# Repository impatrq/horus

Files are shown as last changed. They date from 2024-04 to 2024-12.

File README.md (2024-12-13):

<div align="center">
    
# [HORUS](https://linktr.ee/agro_horus)

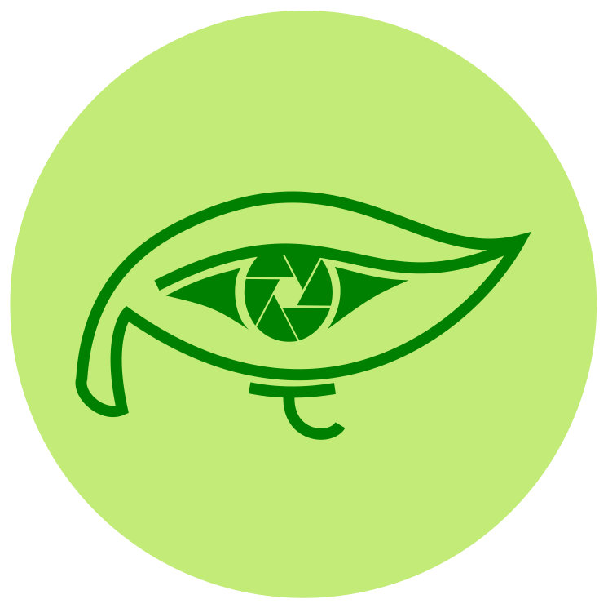
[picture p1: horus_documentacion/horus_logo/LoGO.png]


&nbsp;

| Página web | Email | Instagram | YouTube |
|---|---|---|---|
|[agro_horus.app](https://horus-pagina-web.vercel.app)|agroohoruss@gmail.com|[@agro_horus](https://www.instagram.com/agro_horus/)|[agro_horus.video](https://www.youtube.com/watch?v=Mp89aknXm1M&pp=ygUaaG9ydXMgcm9ib3Qgc2VtaWF1dG9tYXRpY28%3D)|

&nbsp;

</div>

## ¿Qué es Horus?
Horus es un robot de reconocimiento para el campo que permite la detección de plagas de manera remota.

## ¿De dónde surgió la idea?

Comenzamos primero con la idea de ayudar al campo, luego de investigación llegamos a las problemáticas que presentaban las plagas artrópodos en las plantaciones, así llegamos a la conclusión de automatizar el monitoreo de plantaciones con un robot autónomo.

## ¿Cómo funciona?
El robot se translada de manera autónoma por el campo y analiza los cultivos a su alrededor con una cámara. La IA del robot analiza el video que percibe con la cámara y determina si se encuentra con una plaga. Esta información es luego transmitida por radiofrecuencia a un módulo de comunicación que permite conectarlo a una computadora con nuestra aplicación. Esto incluye base de datos para guardar las detecciones, interfaz gráfica e interacción con el robot para el usuario

## ¿Quiénes somos?

Somos un grupo de alumnos de E.E.S.T. N°7 "Taller Regional Quilmes" (IMPA).

<div align="center">
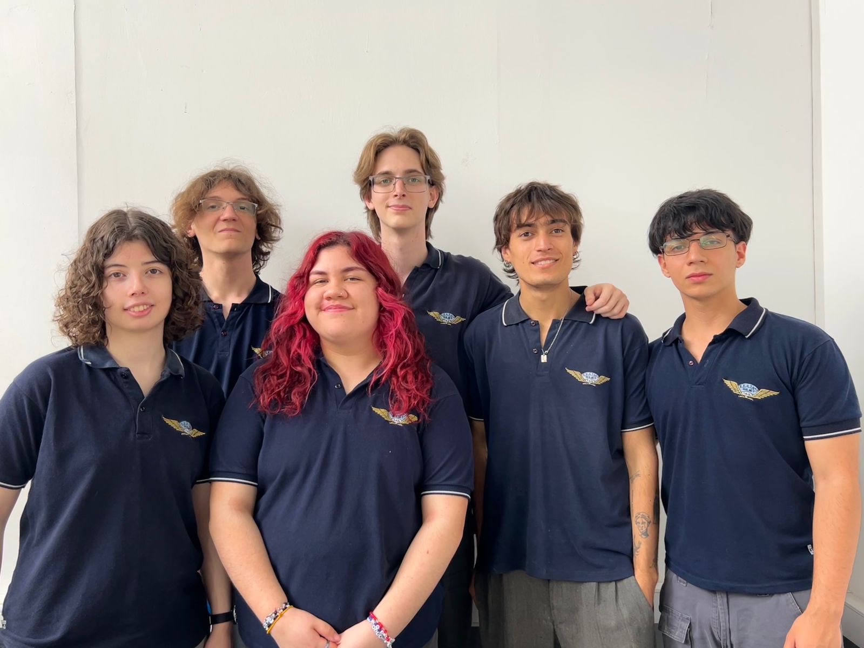
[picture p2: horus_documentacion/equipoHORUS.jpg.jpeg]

</div>

### Cabrera, Martín

* 📧 martincabreracirco@gmail.com

* LinkedIn: https://www.linkedin.com/in/mart%C3%ADn-alejandro-cabrera-6014b727b/

### Contreras, Abril Victoria

* 📷 Instagram: @_ _viicontreras__

* 📧 abrilchiscontreras@gmail.com

* LinkedIn: https://www.linkedin.com/in/abril-contreras-039998303/

### Díaz Steinbrecher, Lara

* 📧 diazsteinbrecher@gmail.com

* LinkedIn: https://www.linkedin.com/in/lara-diaz-steinbrecher-97263b303/

### Ferrante, Santino

* 📧 ferrantesantino14@gmail.com
  
* LinkedIn: https://www.linkedin.com/in/santino-marco-ferrante-a57bb5180/

### Kearney, Mateo

* LinkedIn: https://www.linkedin.com/in/mateo-kearney-996637303/

### Torres, Juan Ignacio

* 📧 juanignaciotorr@gmail.com

* LinkedIn: https://www.linkedin.com/in/juan-ignacio-torres-34a232303/

## Reconocimientos

* Medalla de Oro en PROTOTIPOS - EJE LIBRE de las ONIET 2024

* Medalla de Oro en FEED DE INSTAGRAM de las ONIET 2024

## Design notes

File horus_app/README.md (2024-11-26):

<div align="center">
    
# [HORUS APP](https://linktr.ee/agro_horus)



&nbsp;

</div>

## ¿Qué es HorusAPP?
HorusAPP es la aplicación que se usa en conjunto con Horus para que el usuario pueda interactua con él y el sistema



## Funcionalidades
* Mapa Interactivo
    * Elegir la ubicación del campo a registrar, desplazarse sobre el mapa
    * Visualizar la ubicación de uno o más robots Horus mediante un mapa
    * Insertar y visualizar ubicaciones de trampas de feromonas colocadas por los responsables del campo
    * Insertar y visualizar ubicaciones de áreas de detección que el usuario quiere que cada robot siga
    * Visualizar los reconocimientos de plaga detectados por todos los robots, y filtrar por ellos
    * Todos los marcadores tienen información sobre los mismos al presionarlos
    * Aquellos que se pueden insertar, pueden ser eliminados del sistema con doble click
    * Sistema de guardado offline para su uso en zonas sin conexión a internet
* Base de Datos que permite:
    * Guardar y exportar todos los reconocimientos hechos por todos los robots
    * Visualizar y mantener registro de cada robot, incluida su ubicación, batería y ID
    * Importar imágenes del sistema de almacenamiento externo de cada robot y hacerle zoom
    * Exportar imágenes guardadas en la base de datos como archivo comprimido
    * Filtrar y ordenar los reconocimientos hechos por los diferentes parámetros detectados:
        * Dia
        * Hora
        * Coordenadas
        * Tipo de Plaga
        * ID de Robot
        * ID de Imagen
        * Trampa de feromona
* Modos offline y online para comunicación de datos con el o los robots:
    * Online: cuando el usuario registre un robot, el servidor tratará de usar el módulo comunicador para transmitir por antena hasta conectar con un robot.
    * Offline: el usuario deberá tomar el sistema de almacenamiento externo al robot e importar los archivos de reconocimiento manualmente a la aplicación.



## Requerimientos y dependencias
* 2GB de almacenamiento en la computadora (puede escalar según el uso de la base de datos)
* 1GB de memoria
* Windows 11+, Linux o Mac
* MongoDB Compass v1.44.5
* NodeJS v20.11.1
* Dependencias: 
    * leaflet v1.9.4
    * body-parser v1.20.2
    * cors v2.8.5
    * express v4.19.2
    * mongoose v8.4.0
    * path v0.12.7
    * serialport v12.0.0
    * dotenv v16.4.5
    * @serialport/parser-readline v12.0.0
    * idb v8.0.0
    * jszip v3.10.1
    * vue v3.2.13
    * vue-router v4.0.3
    * @vue/cli-plugin-babel v5.0.0
    * @vue/cli-plugin-router v5.0.0
    * @vue/cli-service v5.0.0
    * concurrently v8.2.2
    * electron v20.2.0
    * wait-on v6.0.1 



## Instrucciones de instalación
Ingrese a la página de github de [Horus](https://github.com/impatrq/horus) y descargue el último lanzamiento. Dentro de la carpeta de horus_app, si su sistema operativo es windows, ejecute (doble click) el archivo Horus.bat; si se encuentra en Linux o Mac, ejecute el archivo Horus.sh. Para su comodidad, cree un acceso directo del archivo ejecutable (ya sea .bat o .sh) para poder acceder más fácilmente al archivo desde su escritorio.



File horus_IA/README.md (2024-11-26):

--------------------
Clonar la carpeta dentro de un entorno virtual

Instalar los requerimentos dentro del entorno
--------------------

Escribir en Terminal: 

cd yolov5

python detect.py --weights orugasmodelo.pt --source 0

(Esto activa la IA como una prueba) pero al ejecutar el main, este la activa automaticamente.

Dentro de la carpeta yolo se encuentra tambien el main.py que es el que horus ejecutara de forma constante.

--------------------

HORUS_IA

Posee la carpeta de los modelos actual y anteriores de la inteligencia artificial, asi como los programas que se utilizaron de prueba o de forma provisoria durante el proceso de creacion del prototipo

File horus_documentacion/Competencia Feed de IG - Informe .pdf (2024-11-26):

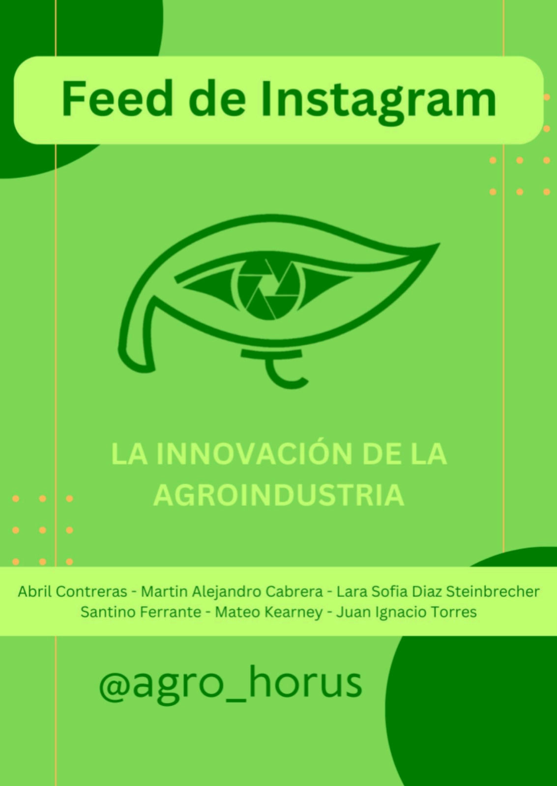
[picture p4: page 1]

### ESCUELA

### EEST N°7, QUILMES BUENOS AIRES

### INTEGRANTES

### ALUMNOS

### CABRERA, Martin Alejandro Cabrera

### CONTRERAS, Abril Victoria

### DIAZ, Lara Sofia Steinbrecher

### TORRES, Juan Ignacio

### DOCENTES

### CARLASSARA, Fabricio MEDINA, Sergio

## @agro_horus

## DESCRIPCIÓN:

Es un robot semi automático que será utilizado en los campos para la detección de plagas en los cultivos, como la soja. Mediante un sistema de reconocimiento artificial e identificación a través de análisis permitirá reconocer: las orugas defoliadoras, las chinches, las arañuelas y los trips, las cuatro principales plagas que pueden estar afectando el cultivo.

## OBJETIVOS DEL PROYECTO:

El objetivo del proyecto es brindar una herramienta que permita a los productores de campo en la Argentina combatir de forma más efectiva las plagas que afectan las cosechas, centrándonos inicialmente en la soja. Para esto, se busca como proyecto diseñar un sistema de reconocimiento artificial e identificación a través del análisis de la cosecha. Esta herramienta permitirá reconocer las 4 plagas artrópodos principales que pueden estar afectando a la planta: las orugas defoliadoras, las chinches, las arañuelas y los trips; y dar un informe detallado al usuario sobre el tipo y donde se encuentra utilizando una aplicación conectada por radiofrecuencia. La implementación de una plataforma móvil robótica permite una eficacia y velocidad mayor en una menor cantidad de tiempo en la que un ser humano podría realizar la misma tarea. La plataforma se traslada con un dispositivo rotatorio que transporta una cámara, la cual se encargará de acercarse a los cultivos para luego ser revisados.

## OBJETIVO DEL FEED DE INSTAGRAM:

Difundir nuestra propuesta y los beneficios que conlleva para el sector agroindustrial y el consumidor.

## INSPIRACIÓN:

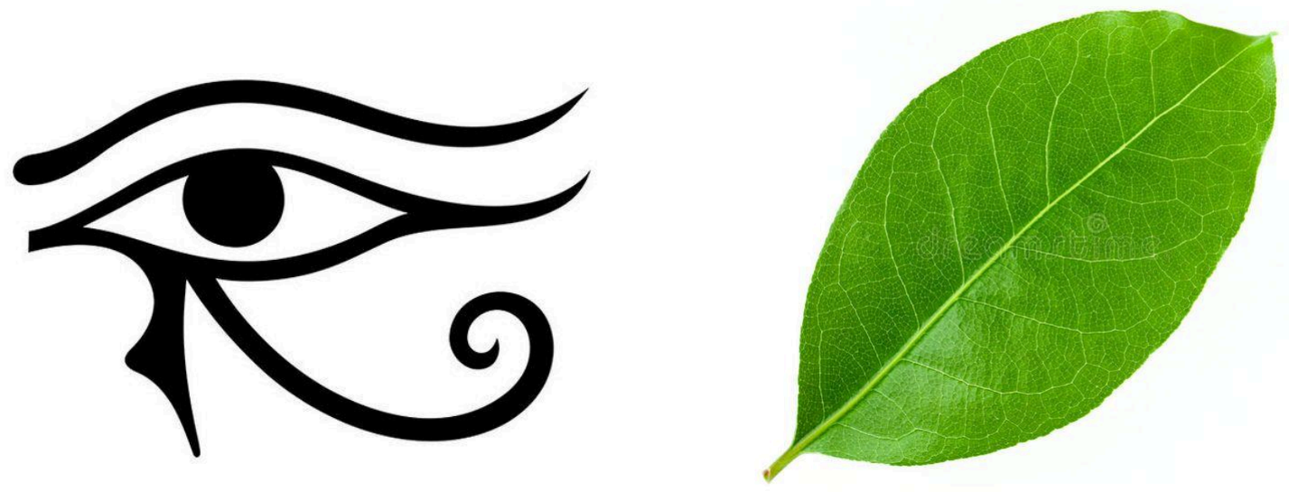
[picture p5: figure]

## BOCETOS DE LOGO:

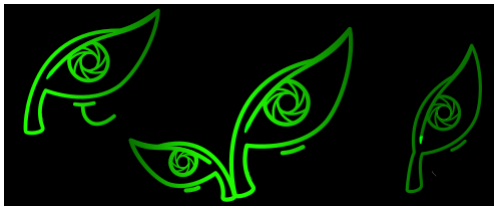
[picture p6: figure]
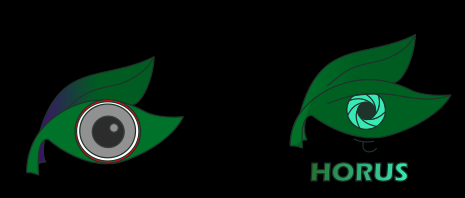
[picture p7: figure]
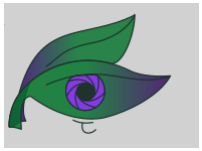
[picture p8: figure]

## LOGO FINAL:

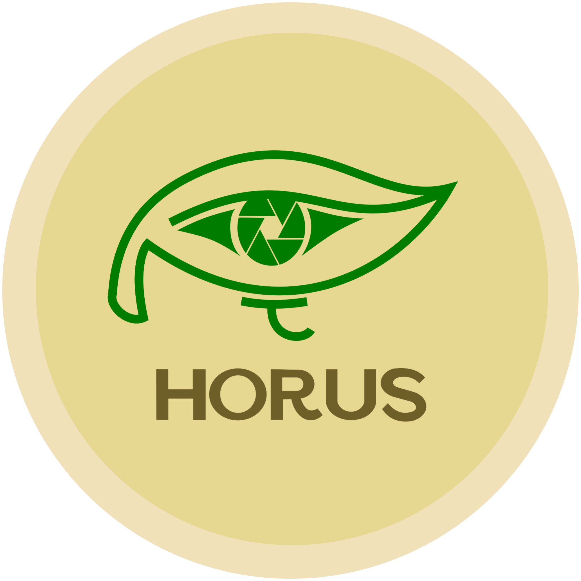
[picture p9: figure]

## FEED DE INSTAGRAM:

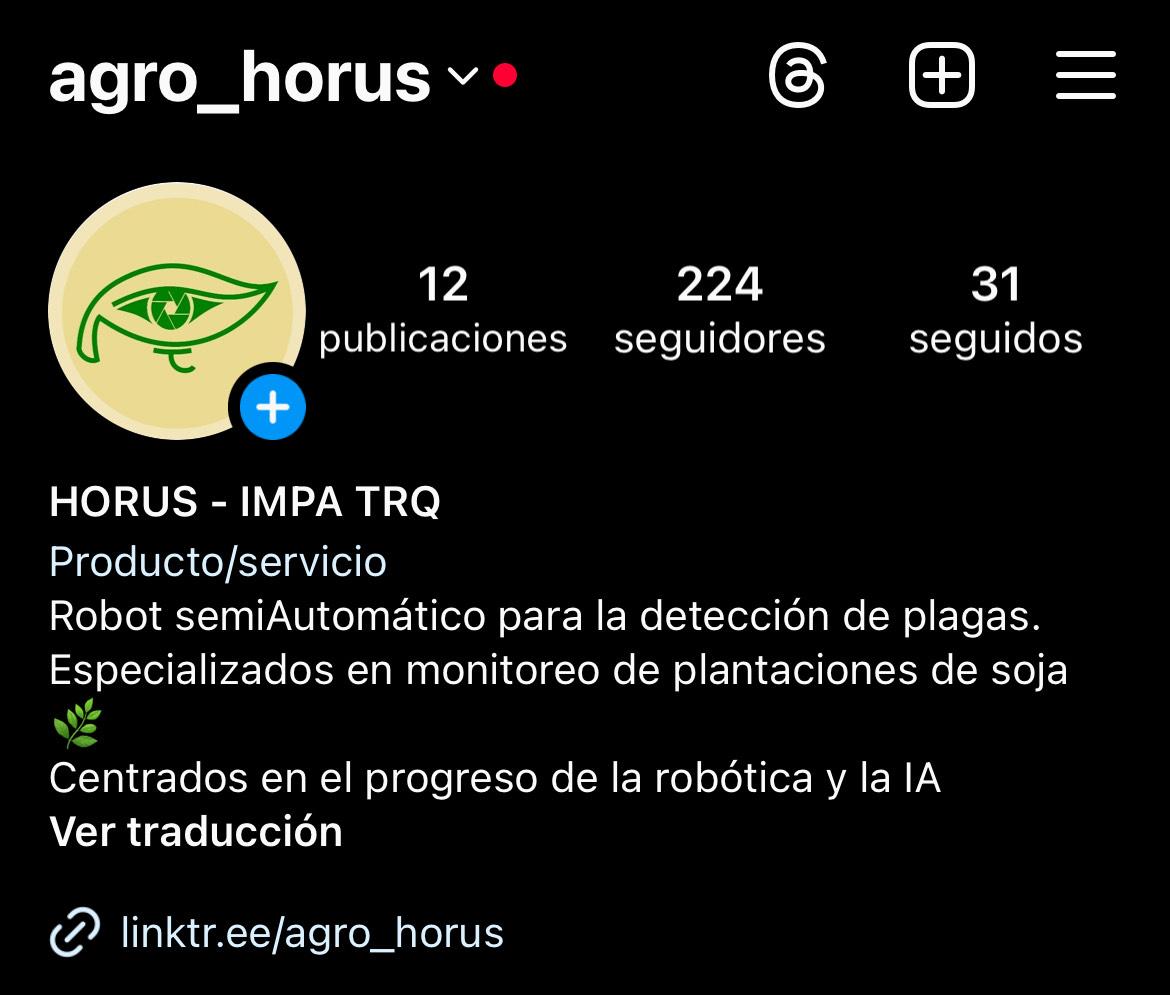
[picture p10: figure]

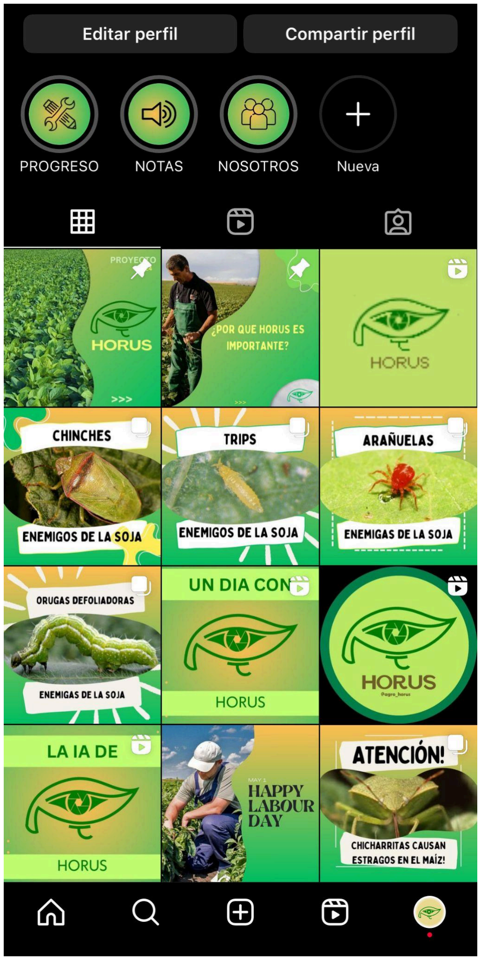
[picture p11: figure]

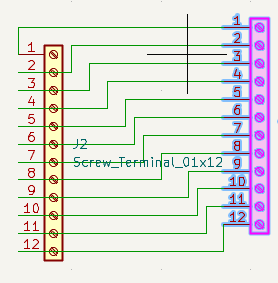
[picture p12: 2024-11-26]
horus_electronics/misc Imagenes/Screenshot_7.png

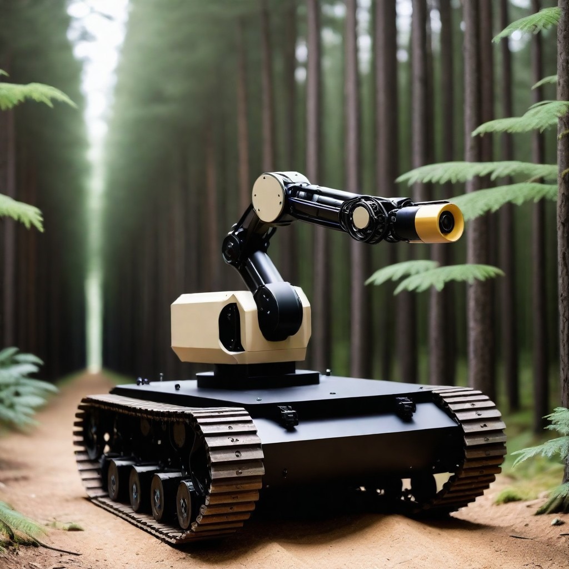
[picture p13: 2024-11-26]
Estructura_HORUS/Primeros diseños/WhatsApp Image 2024-10-21 at 4.15.36 PM.jpeg

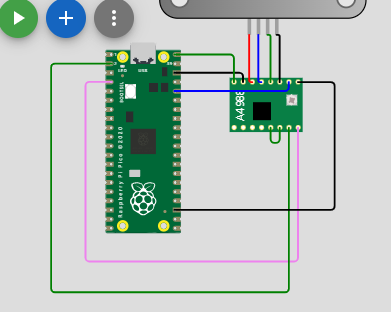
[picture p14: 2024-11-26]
horus_electronics/misc Imagenes/Diagrama conecciones rpipico a4988 stepper.png

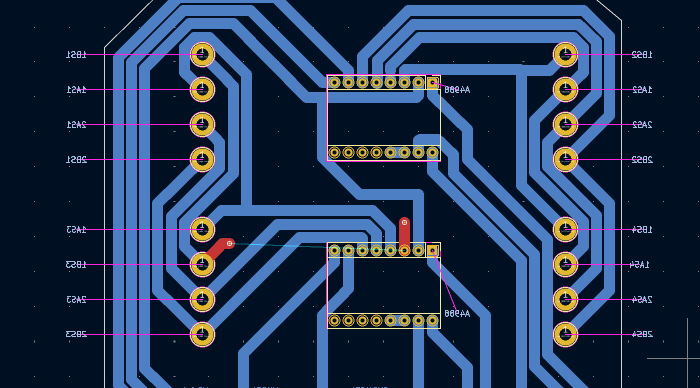
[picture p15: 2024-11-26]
horus_electronics/misc Imagenes/Screenshot_2.png

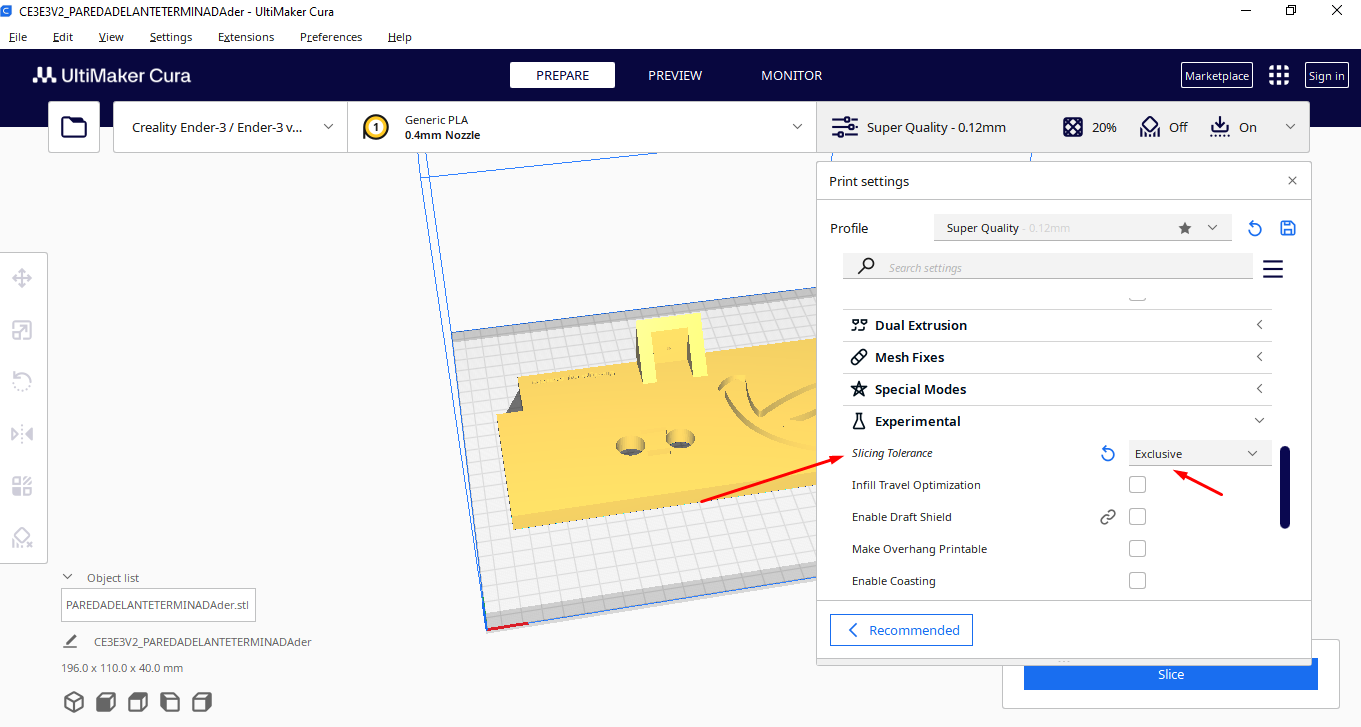
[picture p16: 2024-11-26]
horus_electronics/misc Imagenes/Screenshot_8.png

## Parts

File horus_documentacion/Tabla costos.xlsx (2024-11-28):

Componente | Cantidad | Precio Individual | Precio Parcial | Precio individual USD | Precio Parcial USD
Rasberry P9 4 Modelo B | 1 | $105.701,36 | $105701.36 | $104.87 | $104.87
Raspberry Pi Pico | 2 | $12279.000 | $24558.00 | $12.17 | $24.33
Almacenamiento Externo Kingston | 1 | $12.698,00 | $12698.00 | $12.58 | $12.58
Modulo Lora sx1278 | 2 | $17.487,00 | $34974.00 | $17.35 | $34.70
Filamento Grilon3 PLA Gris | 3 | $14.987,00 | $44961.00 | $14.87 | $44.61
Baterias de Gel 12v | 2 | $23.110,00 | $46220.00 | $22.93 | $45.86
Camara Web Q Plus | 1 | $17.915,00 | $17915.00 | $17.75 | $17.75
Módulo GPS | 1 | $12.638,00 | $12638.00 | $12.54 | $12.54
Modulo A4988 (Drivers) | 2 | $2.079,00 | $4158.00 | $2.06 | $4.12
PCB | 1 | $15900.00 | $15900.00 | $15.75 | $15.75
Plancha de aluminio 30x30 | 1 | $14.498,00 | $14498.00 | $14.36 | $14.36
Cable dupont macho-hembra | 1 | $2.239,00 | $2239.00 | $2.22 | $2.22
Cable dupont macho-macho | 1 | $2.229,00 | $2229.00 | $2.21 | $2.21
Servo Digital Mg996 Mg996r | 2 | $12.100,00 | $24200.00 | $12.00 | $24.00
Tira de Pines | 1 | $3.880,00 | $3880.00 | $3.84 | $3.84
Servo Motor SG90 | 1 | $3.846,00 | $3846.00 | $3.82 | $3.82
Total Pesos (Noviembre 2024): |  |  | $370615.36 | Total USD: | $367.56

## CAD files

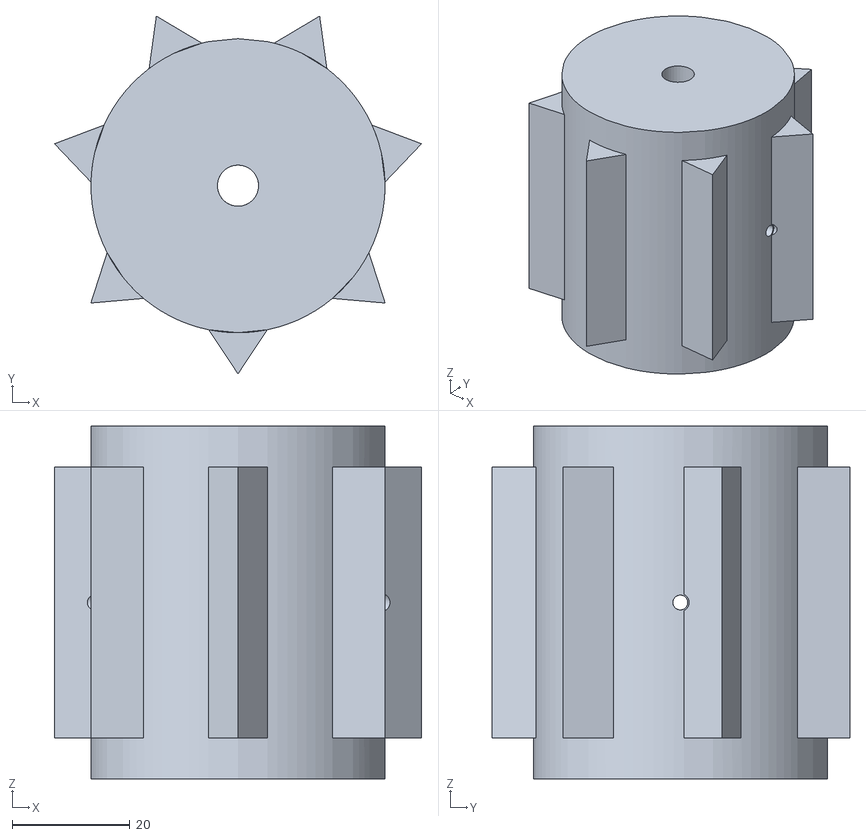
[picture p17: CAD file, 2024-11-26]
Estructura_HORUS/Archivos STL/engranaje ruedas.stl
62.4 x 60.8 x 60.0

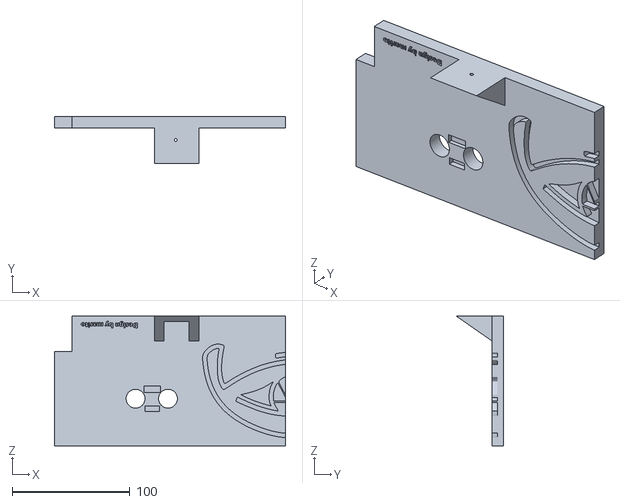
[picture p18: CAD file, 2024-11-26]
horus_electronics/designs/PAREDFRENTEHORUS/PAREDADELANTETERMINADAder.stl
196.0 x 40.0 x 110.0

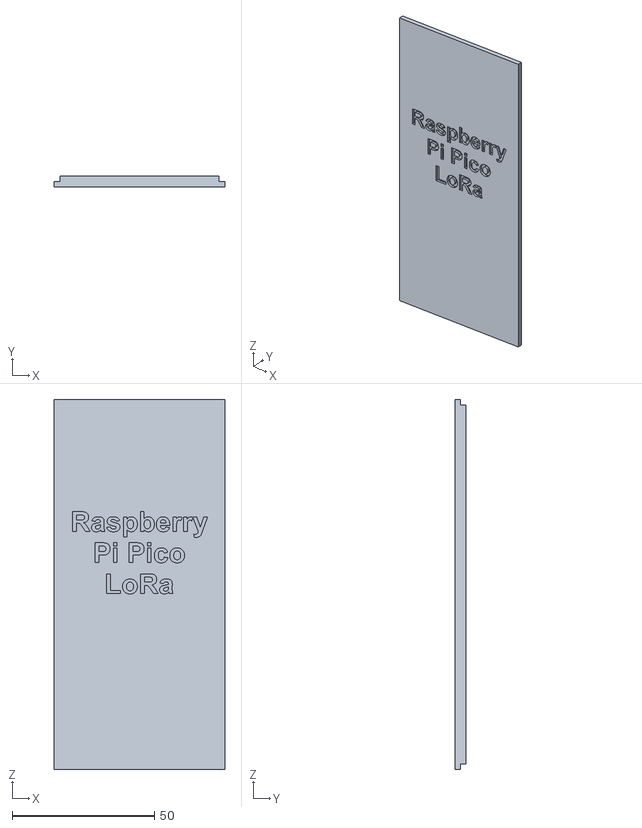
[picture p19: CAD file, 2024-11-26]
horus_electronics/designs/TapaRPIPICOLoRa.stl
60.0 x 4.00 x 130.0

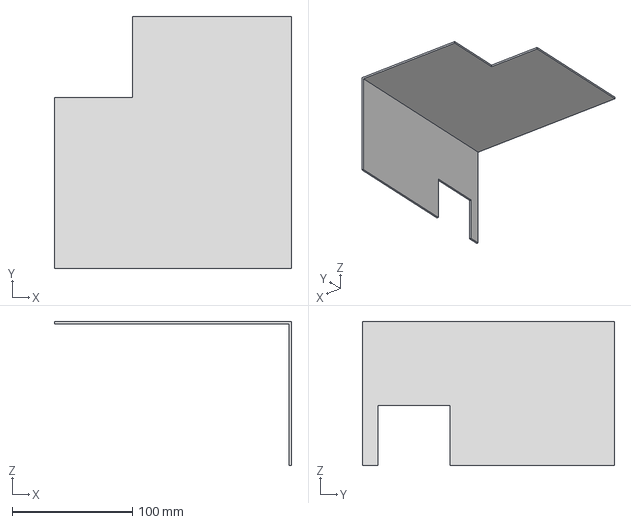
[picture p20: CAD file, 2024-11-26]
Estructura_HORUS/Archivos STL/base atras izq.3mf
197.5 x 210.0 x 120.0 mm

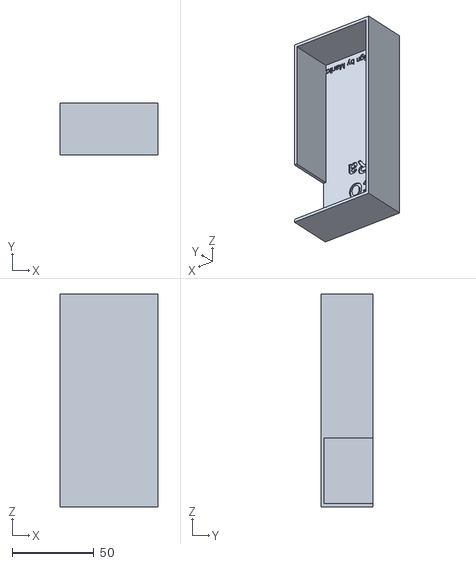
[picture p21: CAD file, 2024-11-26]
horus_electronics/designs/Carcasa RpiPicoLoRa.stl
60.0 x 32.0 x 130.0

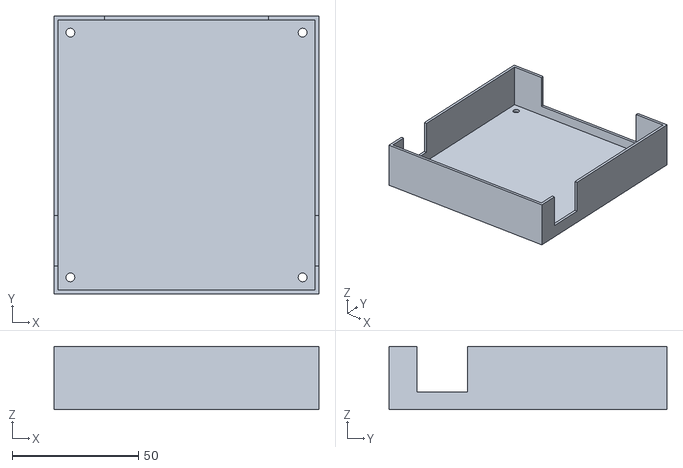
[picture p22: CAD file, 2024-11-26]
Estructura_HORUS/Archivos STL/carcasa controladora sttepers.stl
105.0 x 110.0 x 25.0

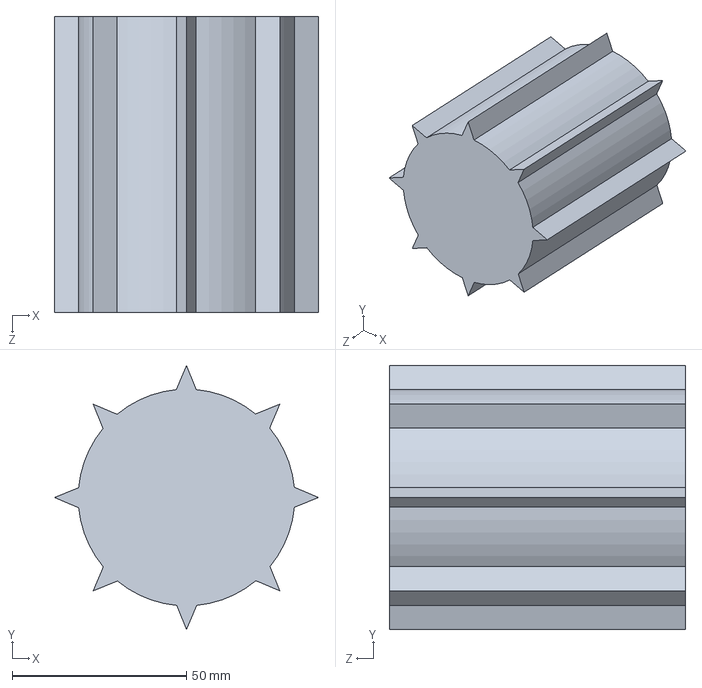
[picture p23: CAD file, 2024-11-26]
horus_electronics/designs/engraneorugas.SLDPRT
75.8 x 75.8 x 85.0 mm

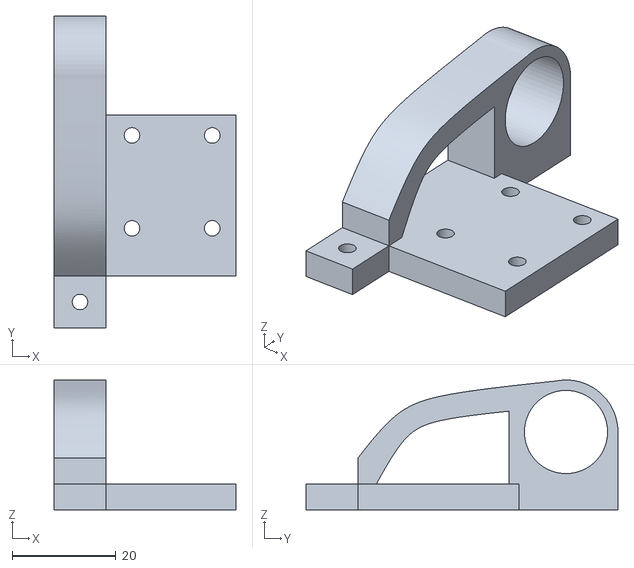
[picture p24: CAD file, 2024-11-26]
Estructura_HORUS/Archivos STL/tessor final.stl
35.0 x 60.0 x 25.0

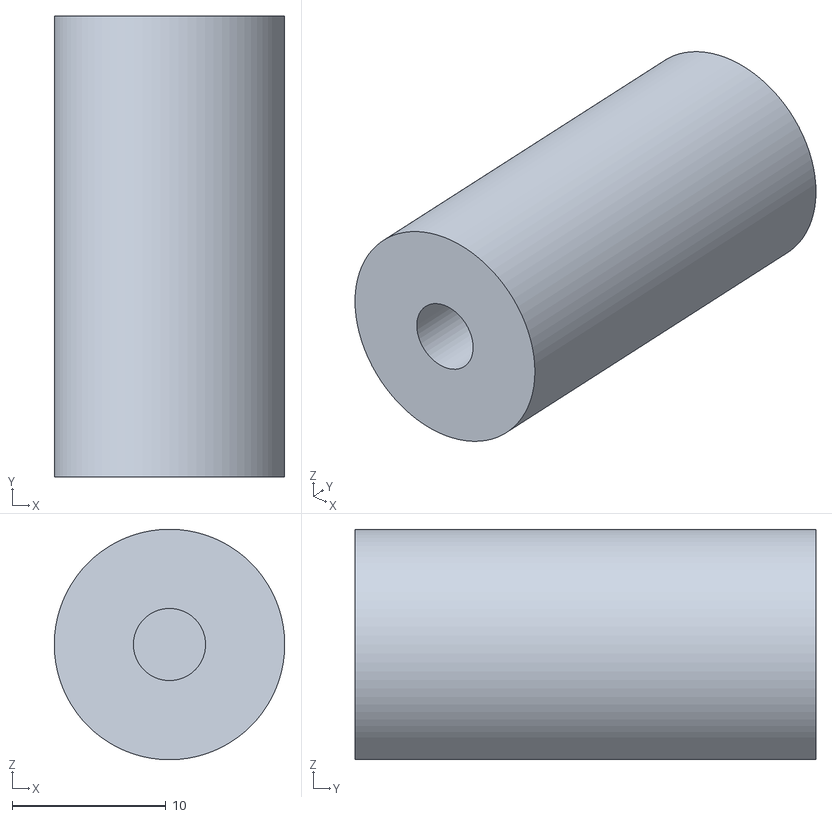
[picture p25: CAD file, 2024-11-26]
Estructura_HORUS/Archivos STL/adaptador eje.stl
15.0 x 30.0 x 15.0

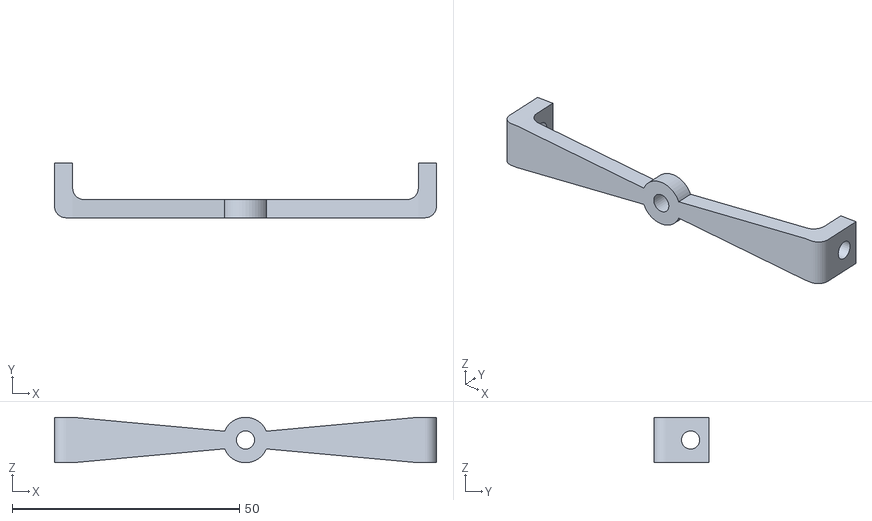
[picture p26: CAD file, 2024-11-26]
Estructura_HORUS/Archivos STL/agarre tuerca elevador de camara.stl
84.0 x 12.0 x 10.0

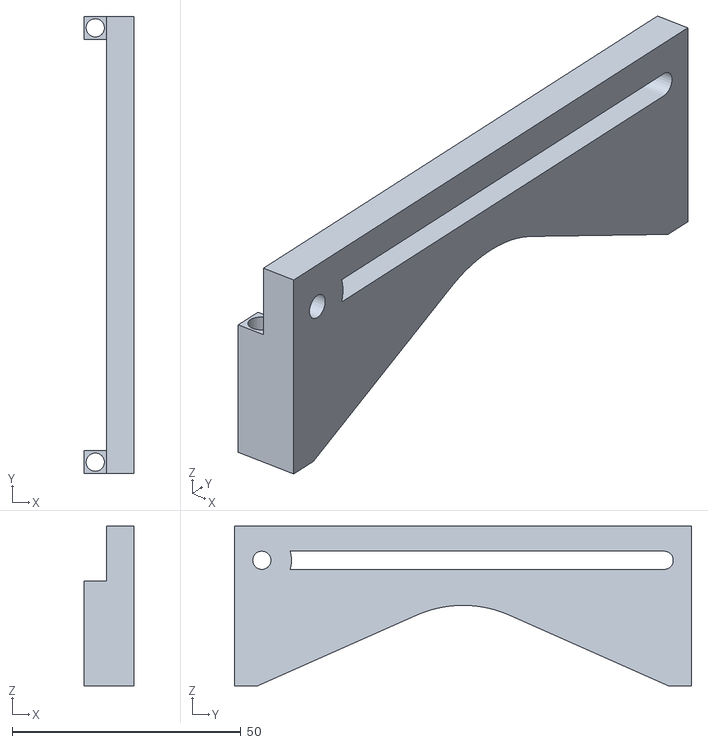
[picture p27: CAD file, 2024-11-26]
Estructura_HORUS/Archivos STL/guia brazo elevador.stl
11.0 x 100.0 x 35.0

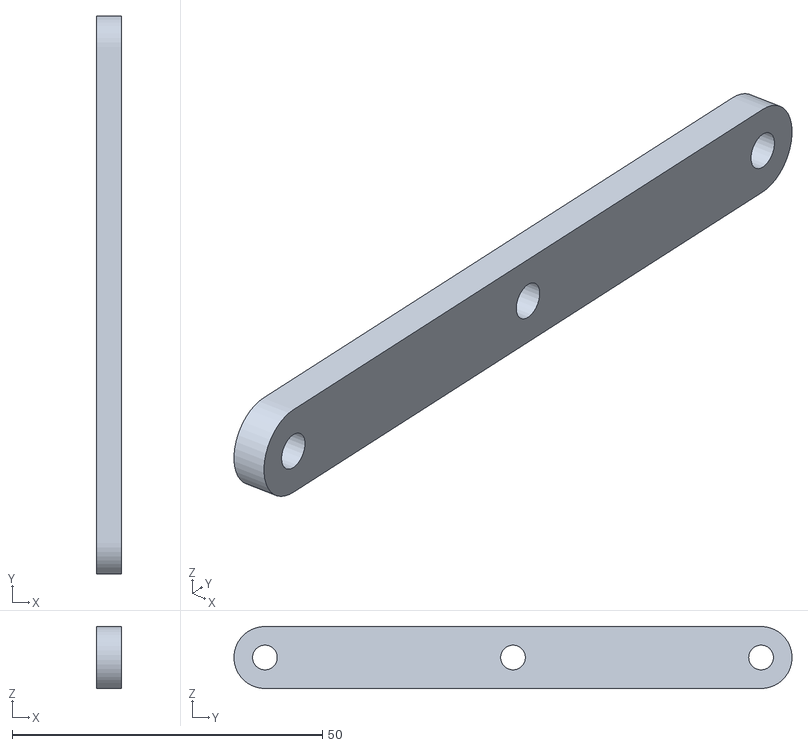
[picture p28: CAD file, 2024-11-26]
Estructura_HORUS/Archivos STL/brazos elevador camara.stl
4.00 x 90.0 x 10.0

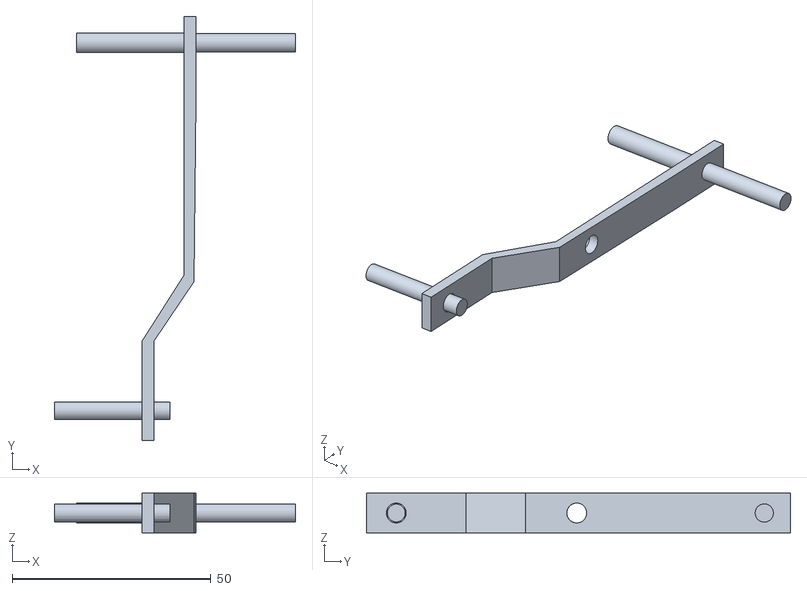
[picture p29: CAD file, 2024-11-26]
Estructura_HORUS/Archivos STL/brazo de suspencion v8.stl
60.6 x 106.6 x 10.0

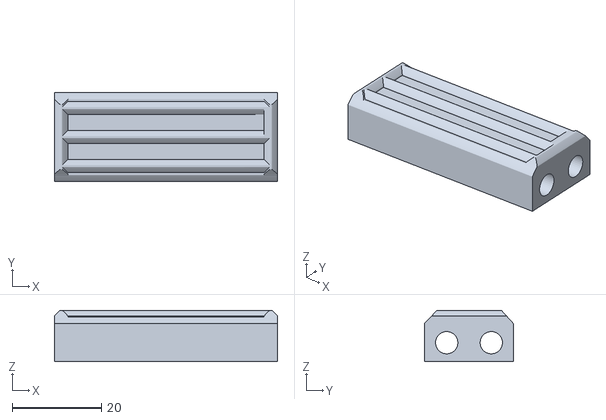
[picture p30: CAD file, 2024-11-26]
Estructura_HORUS/Archivos STL/oruga principal.stl
50.0 x 20.0 x 11.5

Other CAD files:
horus_electronics/designs/PAREDFRENTEHORUS/PAREDADELANTETERMINADAizq.stl
Estructura_HORUS/Archivos STL/base delantera izq.3mf
Estructura_HORUS/Archivos STL/estrcutura principal susp 1.stl
Estructura_HORUS/Archivos STL/soporte baterias.stl
Estructura_HORUS/Archivo tipo .F3D/adaptador eje v1.f3d
Estructura_HORUS/Archivo tipo .F3D/agarre de tuerca v2 brazo elevador.f3d
Estructura_HORUS/Archivo tipo .F3D/base brazo elevador.f3d
Estructura_HORUS/Archivo tipo .F3D/brazo armado.f3z
Estructura_HORUS/Archivo tipo .F3D/brazos v3 elevador camara.f3d
Estructura_HORUS/Archivo tipo .F3D/controladora sttepers (v1~recovered).f3d
Estructura_HORUS/Archivo tipo .F3D/engranaje v5.f3d
Estructura_HORUS/Archivo tipo .F3D/guia v5 brazo.f3d
Estructura_HORUS/Archivo tipo .F3D/oruga v3.f3d
Estructura_HORUS/Archivo tipo .F3D/refuerzo estructura brazo elevador.f3d
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

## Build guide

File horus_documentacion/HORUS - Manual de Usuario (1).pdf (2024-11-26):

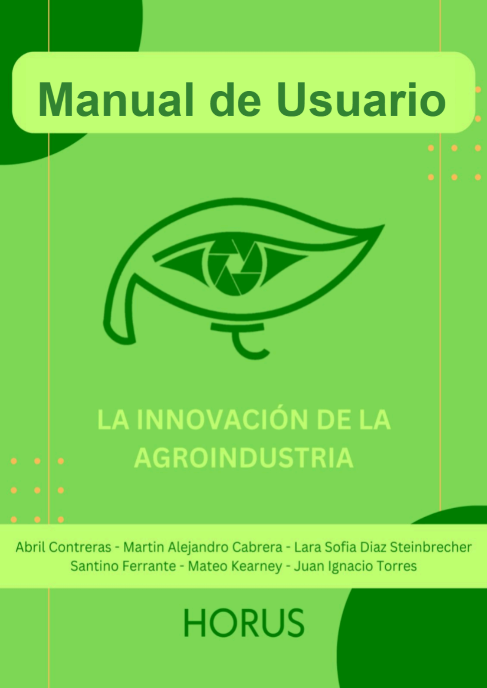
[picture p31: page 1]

# ÍNDICE

ㅡ
INTRODUCCIÓN OBJETIVO

ELEMENTOS

PRECAUCIONES

03

ㅡ
GUIA DE USO
APLICACIÓN

INSTALACIÓN
USO DE INTERFAZ
HOME
ROBOTS
DATA
GALLERY
SETTINGS

04

ㅡ
GUIA DE USO
ROBOT

CONFIGURACIÓN
DESPLIEGUE
MANTENIMIENTO

09

ㅡ
CONTACTOS

10

## INTRODUCCIÓN

OBJETIVO
HORUS es un robot de reconocimiento de plagas del campo por medio de inteligencia artificial. Este documento presenta una guía para el uso del robot y una guía para la aplicación

ELEMENTOS

Los elementos con los que debe de contar el usuario tras recibir el producto son:

- Robot
- Módulo comunicador

REQUERIMIENTOS

Los requerimientos necesarios para la utilización del sistema son

- Cable USB
- Computadora
- 2GB de almacenamiento en la computadora (puede escalar según el uso de la base de datos)
- 1GB de memoria
- Windows 11+, Linux o Mac
- MongoDB v7.0.9
- NodeJS v20.11.1
- Dependencias:
- leaflet v1.9.4
- body-parser v1.20.2
- cors v2.8.5
- express v4.19.2
- mongoose v8.4.0
- path v0.12.7
- serialport v12.0.0
- dotenv v16.4.5
- @serialport/parser-readline v12.0.0

- idb v8.0.0
- jszip v3.10.1
- vue v3.2.13
- vue-router v4.0.3
- @vue/cli-plugin-babel v5.0.0
- @vue/cli-plugin-router v5.0.0
- @vue/cli-service v5.0.0
- concurrently v8.2.2
- electron v20.2.0
- wait-on v6.0.1

## GUIA DE USO - APLICACIÓN

INSTALACIÓN
Ingrese al repositorio público de Github [https://github.com/impatrq/horus] y descargue el último lanzamiento de la aplicación. Extraiga el archivo .zip en el lugar de su computadora donde le sea fácil encontrarlo, como en Documentos. Ingrese a la carpeta horus_app y seleccione el ejecutable correspondiente:
- Si usa Windows, use el archivo Horus.bat
- Si usa Linux o Mac, use el archivo Horus.sh
Ejecutarlo (o doble click) iniciará la aplicación. Es recomendable que cree un acceso directo de este archivo en su escritorio para que sea más fácil ingresar desde su computadora.
Antes de iniciar la aplicación, asegúrese de conectar el módulo comunicador con el puerto USB correspondiente de la computadora. Espere el inicio de la aplicación, y le será presentada la siguiente interfaz

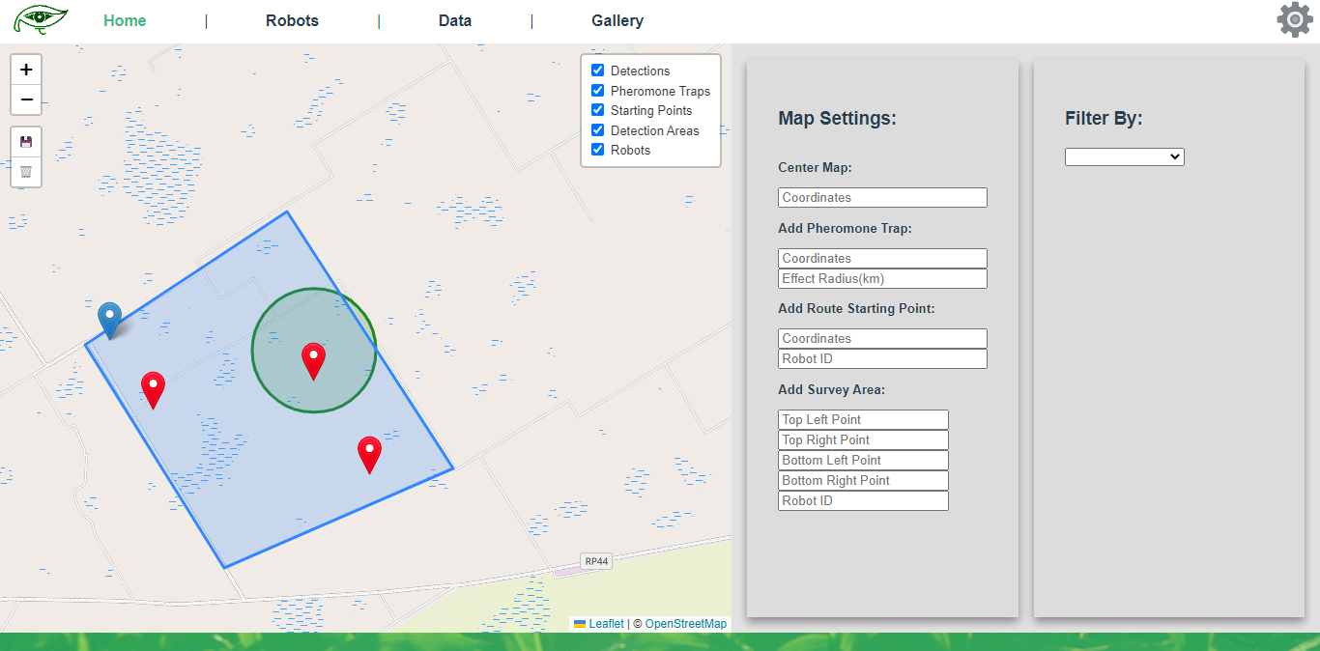
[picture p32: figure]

Esta interfaz presenta diferentes subinterfaces. Las mismas se encuentran descriptas a continuación.

HOME
La pestaña de HOME presenta un mapa con toda la información principal de la aplicación. Del lado izquierdo, se encuentra un mapa que presenta diferentes datos como:
- Ubicación de los robots (marcador violeta)
- Ubicación de trampas de feromonas (círculo verde)
- Áreas de detección de cada robot (cuadrilátero azul)
- Puntos de partida para cada robot (marcador azul)
- Ubicación de detecciones (marcador rojo)
El mapa tiene funcionalidades de zoom por medio de los controles en la esquina superior izquierda. Debajo de los mismos se encuentran dos botones que le permiten al mapa funcionar de manera offline; el de arriba le permite guardar la parte del mapa que se encuentra viendo, y el de abajo le permite eliminarlos.Los controles de la esquina superior derecha permiten mostrar u ocultar los diferentes marcadores en el mapa. Los marcadores correspondientes a las trampas de feromonas, los puntos de partida y las áreas de reconocimiento pueden ser eliminados con doble click. Presionar un marcador le permitirá visualizar las coordenadas del mismo.
Del lado derecho de la pestaña, se pueden controlar los marcadores que se muestran en el mapa. El filtro permite filtrar que detecciones se muestran en el mapa, mediante uno o más requerimientos para los marcadores. La configuración del mapa tiene varias funciones, en orden:
- Centrar mapa: elija coordenadas en formato [x,y] como el centro del mapa. Esto lo debe usar la primera vez que inicia la aplicación para elegir las coordenadas de su sector general a reconocer.
- Agregar trampa de feromona: ingrese coordenadas en formato [x,y] para agregar una trampa de feromona al mapa y el radio de efecto que tiene.
- Agregar punto de partida de ruta: ingrese coordenadas en formato [x,y] e ingrese el robot al que estará asignado por medio de su ID. Este es el punto desde el cual el robot se desplazará.
- Agregar área de reconocimiento: ingrese cuatro pares coordenadas en formato [x,y] para formar un polígono, el cual el robot asignado por ID recorrerá.
ROBOTS
La pestaña de ROBOTS permite conectar uno o más robots a la aplicación y visualizar los datos relevantes de los mismos. Cuando inicia la aplicación por primera vez o cuando suma un robot a su tropa, seleccione el botón para agregar un nuevo perfil de robot. Espere a que el servidor conecte con el robot. Una vez conectado, le mostrará la información relevante del robot. Si desea eliminar uno de los robots, presione el botón rojo correspondiente al robot que quiere eliminar y se lo borrará del sistema.

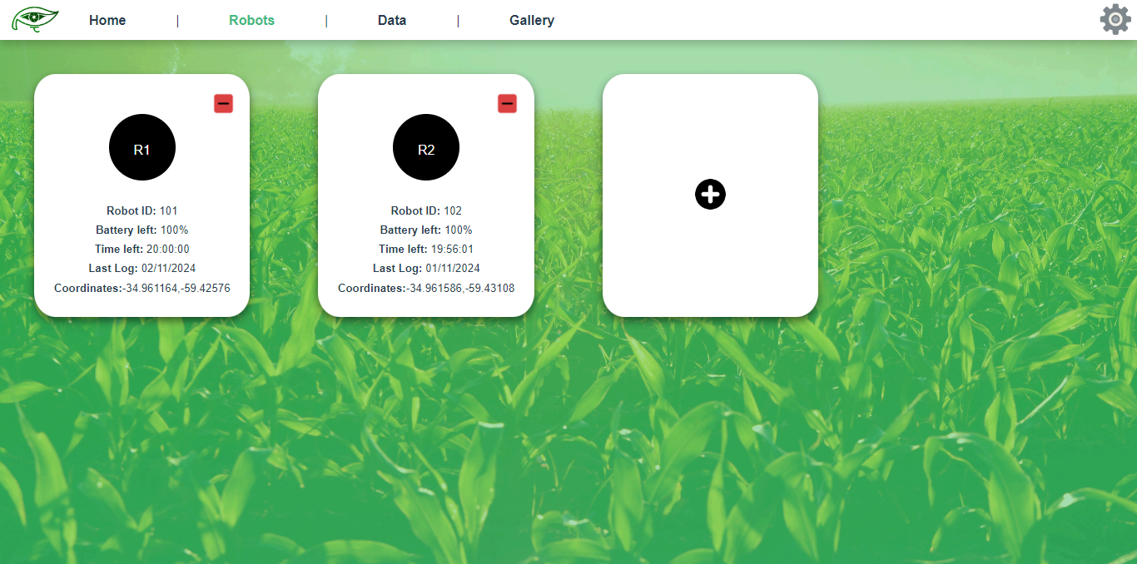
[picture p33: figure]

Si el servidor no puede conectar, el perfil del robot mostrará que hay un error al conectarse al servidor. Si el servidor no se logra conectar con el robot, mostrará que la información no se encuentra disponible (unavailable). En ese caso, tome su tiempo y remueva los obstáculos para que se conecte el servidor apropiadamente, o opte por usar el modo de funcionamiento offline, detallado en la sección de Ajustes(Settings).

DATA
La pestaña de DATA permite visualizar las detecciones detectadas por el robot en forma de logs. Las detecciones tienen los siguientes datos:
- Date: el día en el que detectó
- Time: la hora a la que se detectó
- Image ID: el ID de imágen. Permite buscarlo en el ID de galería o en el almacenamiento del robot
- Robot ID: número de identificación propio del robot
- Plague Type: tipo de plaga detectada
- Pheromone Trap: si fue detectado o no cerca de una trampa de feromona
- Probability: que probabilidad le asigna la IA que sea una plaga
- Coordinates: coordenadas del robot cuando se detectó la plaga

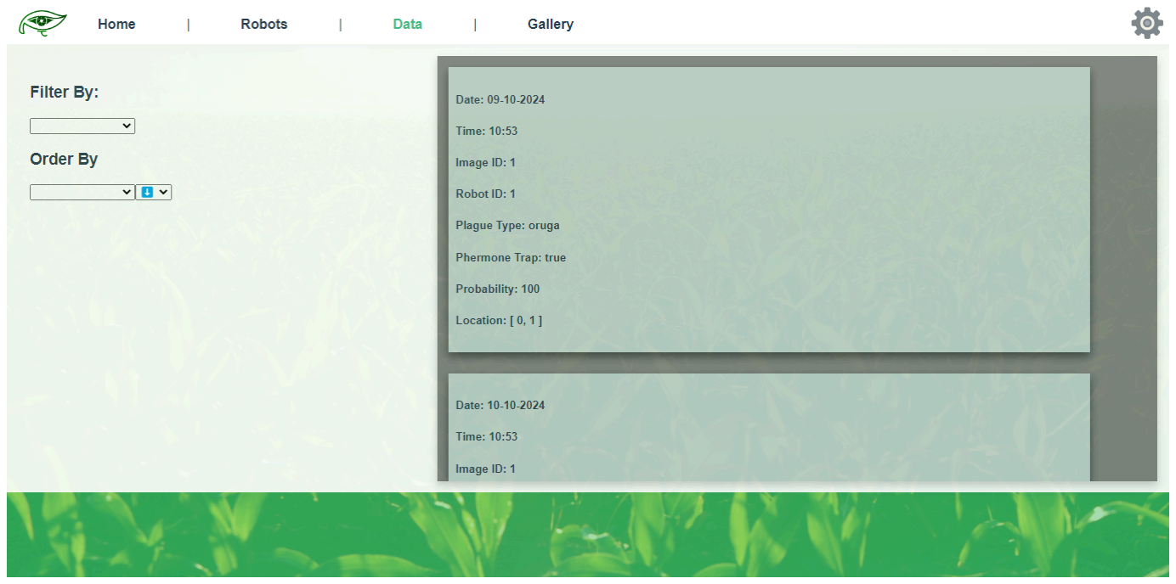
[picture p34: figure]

Del lado derecho, se muestran todas las detecciones guardadas en forma de lista. Del lado izquierdo, tiene dos secciones; una que le permite filtrar por las diferentes detecciones para buscar ciertas en específico y otra que le permite ordenar cuales se muestran primero.
Para la función de filtro, seleccione la característica por la que quiere filtrar.

El botón que aparecerá le permitirá seleccionar el valor que querrá que posean los logs que se muestran. Varias características pueden ser seleccionadas a la vez. Para eliminar una de las características por las que filtrar, seleccione el botón rojo junto al botón de la característica correspondiente.
Para la función de orden, selecciona una característica por la que querrá ordenar, y seleccione ascendente(⬆️) o descendente(⬇️), para cambiar el orden.

GALLERY

La galería le permite visualizar las imágenes grabadas por el
robot. El botón | le permitirá cargar las imágenes a la aplicación,
para lo cual necesitará conectar el almacenamiento externo a uno de los puertos USB de la computadora. Para esto, le requerirá seleccionar todas las imágenes de la carpeta del almacenamiento externo. Una vez seleccionadas, las imágenes serán guardadas en la galería.
El botón | exportará todas las imágenes guardadas en la aplicación
en formato de archivo comprimido .zip, que podrá guardar en otro lugar de la computadora o en otro al almacenamiento externo.
Cada imágen posee su ID de imagen (Image ID) debajo para identificarse. Al ser clickeadas, las imágenes se mostrarán más agrandadas.

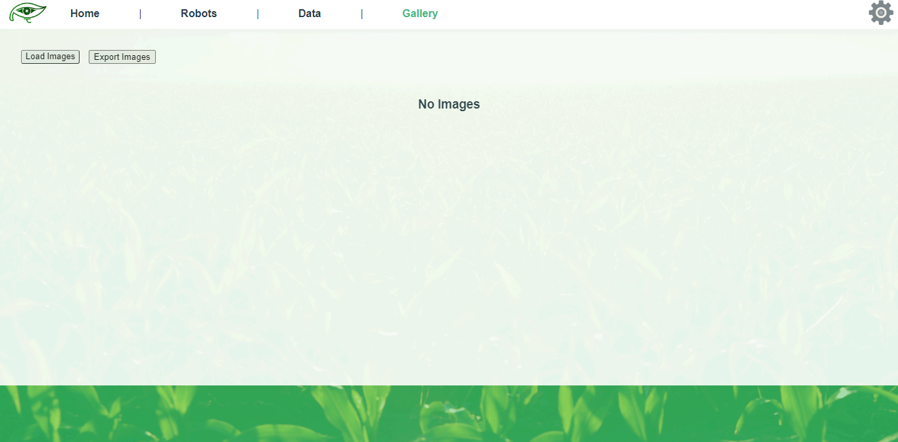
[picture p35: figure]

SETTINGS
La pestaña de ajustes posee diferentes funcionalidades auxiliares para el usuario.
- HELP: este botón le permitirá visualizar el manual de usuario en caso que pierda acceso al mismo.
- EXPORT LOGS: este botón le permitirá exportar la base de datos en formato .json para poder guardarla en otro sitio del ordenador o un almacenamiento externo.
- IMPORT LOGS: este botón le permitirá importar los logs manualmente en vez de recibirlo por radiofrecuencia. Esto se conoce como funcionamiento offline del robot. Para usarlo debe seguir los siguientes pasos:

1. Desde la ruta de Home, asígnele un área de reconocimiento (survey area) y un punto de partida (starting point) al robot que desea usar
2. Conecte el almacenamiento externo del robot que quiere registrar a su computadora y presione el botón de IMPORT LOGS. Seleccione el almacenamiento externo, y dentro del mismo, el archivo tx.json.
3. El sistema procesará el archivo y le devolverá un rx.json. Colóquelo en el almacenamiento externo (ya sea creándolo o sobreescribiendo)
4. Lleve al robot al punto de partida. El mismo comenzará a registrar
5. Una vez finalice, debido a que no tiene acceso a su ubicación, deberá rodear el área de reconocimiento para buscar (comience del lado opuesto desde el que empezó en sentido horario)
6. Remueva el almacenamiento externo del robot y coloquelo nuevamente en la computadora.
7. Desde IMPORT LOGS, seleccione el mismo archivo, tx.json. Si el robot hizo alguna detección, se actualizará la base de datos y el mapa. Los datos del robot que se muestran en los perfiles también se actualizarán. Si quiere cambiar el área de detección o el punto de inicio, hágalo antes de presionar IMPORT LOGS. Una vez actualizado, le pedirá que sobreescriba el archivo rx.json del robot.
- CONTACTS: este botón le redirigirá a nuestra página web para acceder a nuestro principal medio de difusión.

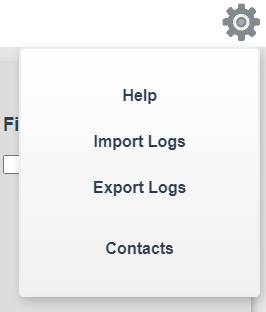
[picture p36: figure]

## GUIA DE USO - ROBOT

ARMADO DE ROBOT

DESARMADO DE ROBOT

Retire la tapa superior del robot con cuidado,

CONFIGURACIÓN

Conecte el módulo comunicador por cable USB al puerto COM3 de la computadora. Mediante la aplicación, conecte al robot y regístrelo en la aplicación.

DESPLIEGUE

Coloque un pendrive en una de las ranuras usb de la raspberry pi 4 central para que las imágenes sean almacenadas ahí.
Una vez conectado con la aplicación, elija un punto de partida y un área a reconocer. Luego coloque el robot en el punto de partida indicado. El robot se desplazará por el área a reconocer a partir del mismo. Una vez finalice el recorrido, use el mapa de la aplicación para ubicarlo y retirarlo.

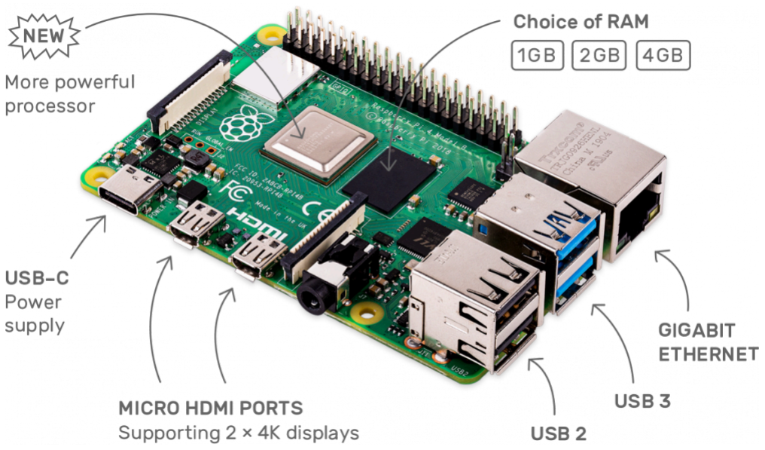
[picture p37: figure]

Una vez que saque el pendrive y pase los archivos a la aplicación, borrelos completamente del pendrive y vuelva a insertarlo en el robot.

MANTENIMIENTO
Las baterías del robot reducirán su carga con el tiempo. Guíese con la carga de batería visible en la pestaña de ROBOTS de la aplicación, en el perfil del robot correspondiente. Desconecte las baterías (bornera gnd - 12v) y cargarlas a partir del %. Revise la vida útil de las baterías y reemplácelas acordemente.

ERRORES COMUNES Y SOLUCIONES

Desconexión de cables
Sección de Raspberry Pi 4:
Sección de placa Pangea:
Sección de módulo comunicador:

Orugas Trabadas

RIESGOS

Oxidación conexión con baterías Polvo

## ESQUEMA DE UTILIDAD

## CONTACTOS

Ante cualquier consulta, puede contactar a nuestro equipo mediante los siguientes medios:
agroohoruss@gmail.com
https://horus-pagina-web.vercel.app

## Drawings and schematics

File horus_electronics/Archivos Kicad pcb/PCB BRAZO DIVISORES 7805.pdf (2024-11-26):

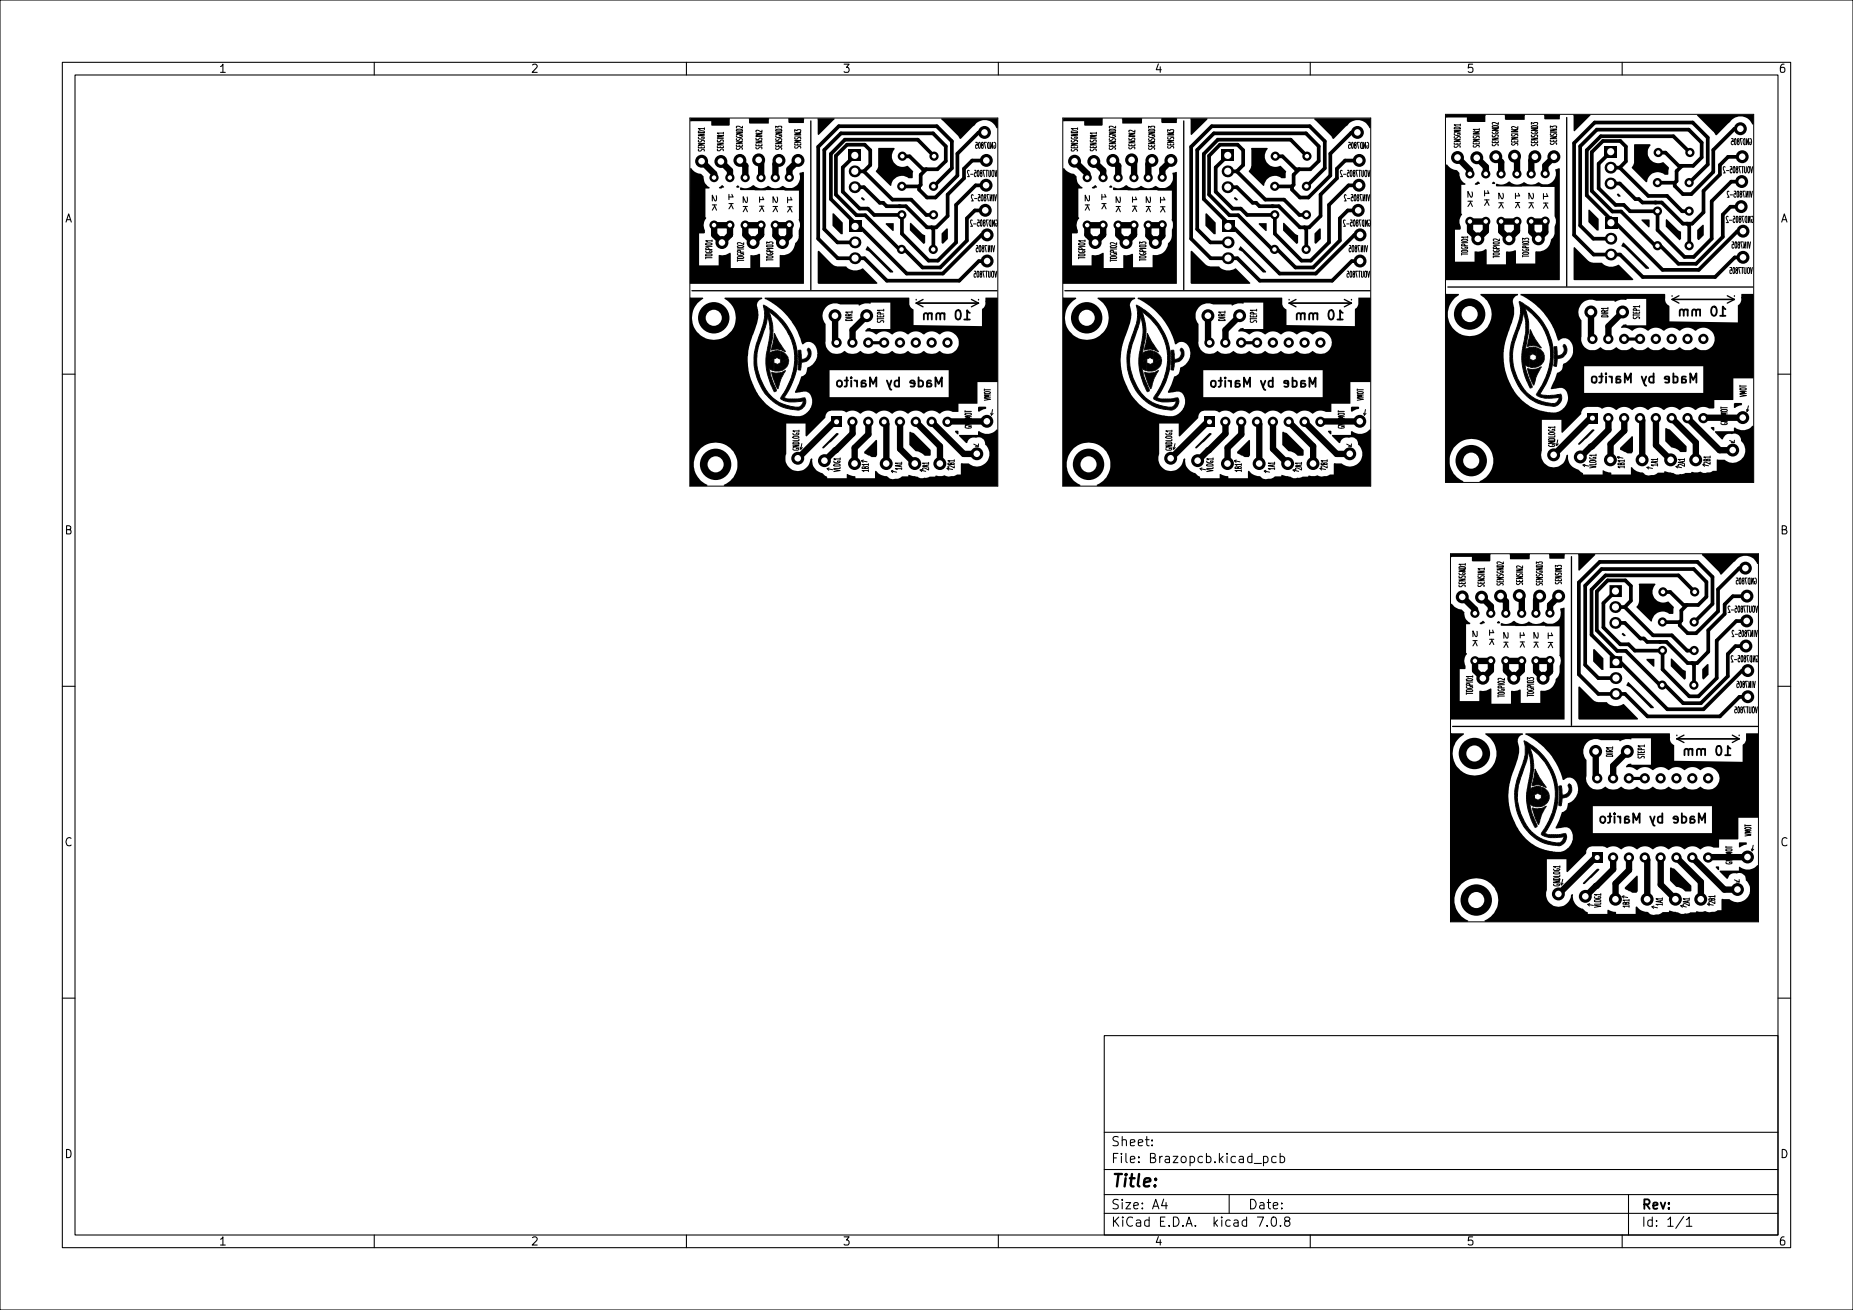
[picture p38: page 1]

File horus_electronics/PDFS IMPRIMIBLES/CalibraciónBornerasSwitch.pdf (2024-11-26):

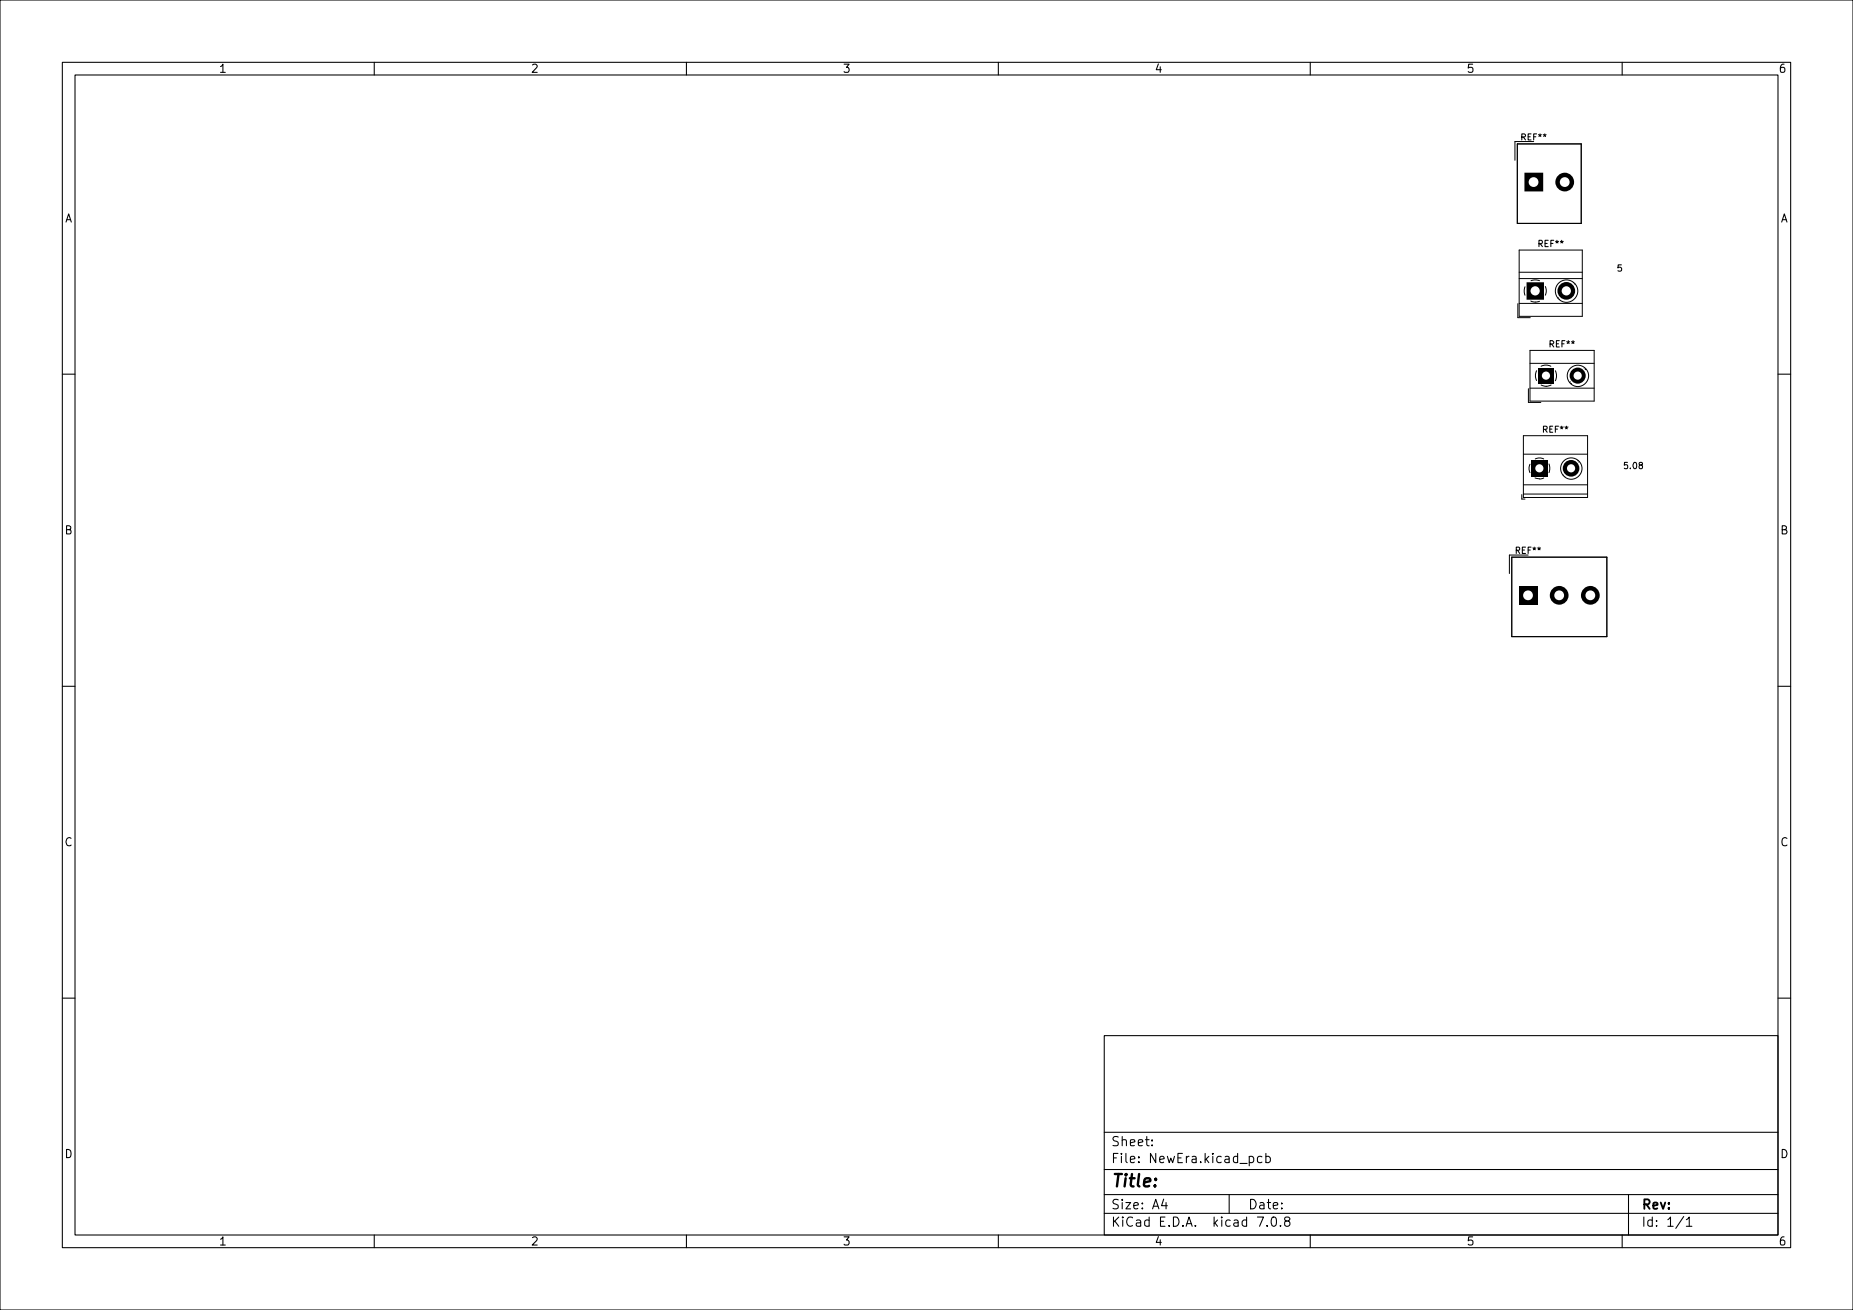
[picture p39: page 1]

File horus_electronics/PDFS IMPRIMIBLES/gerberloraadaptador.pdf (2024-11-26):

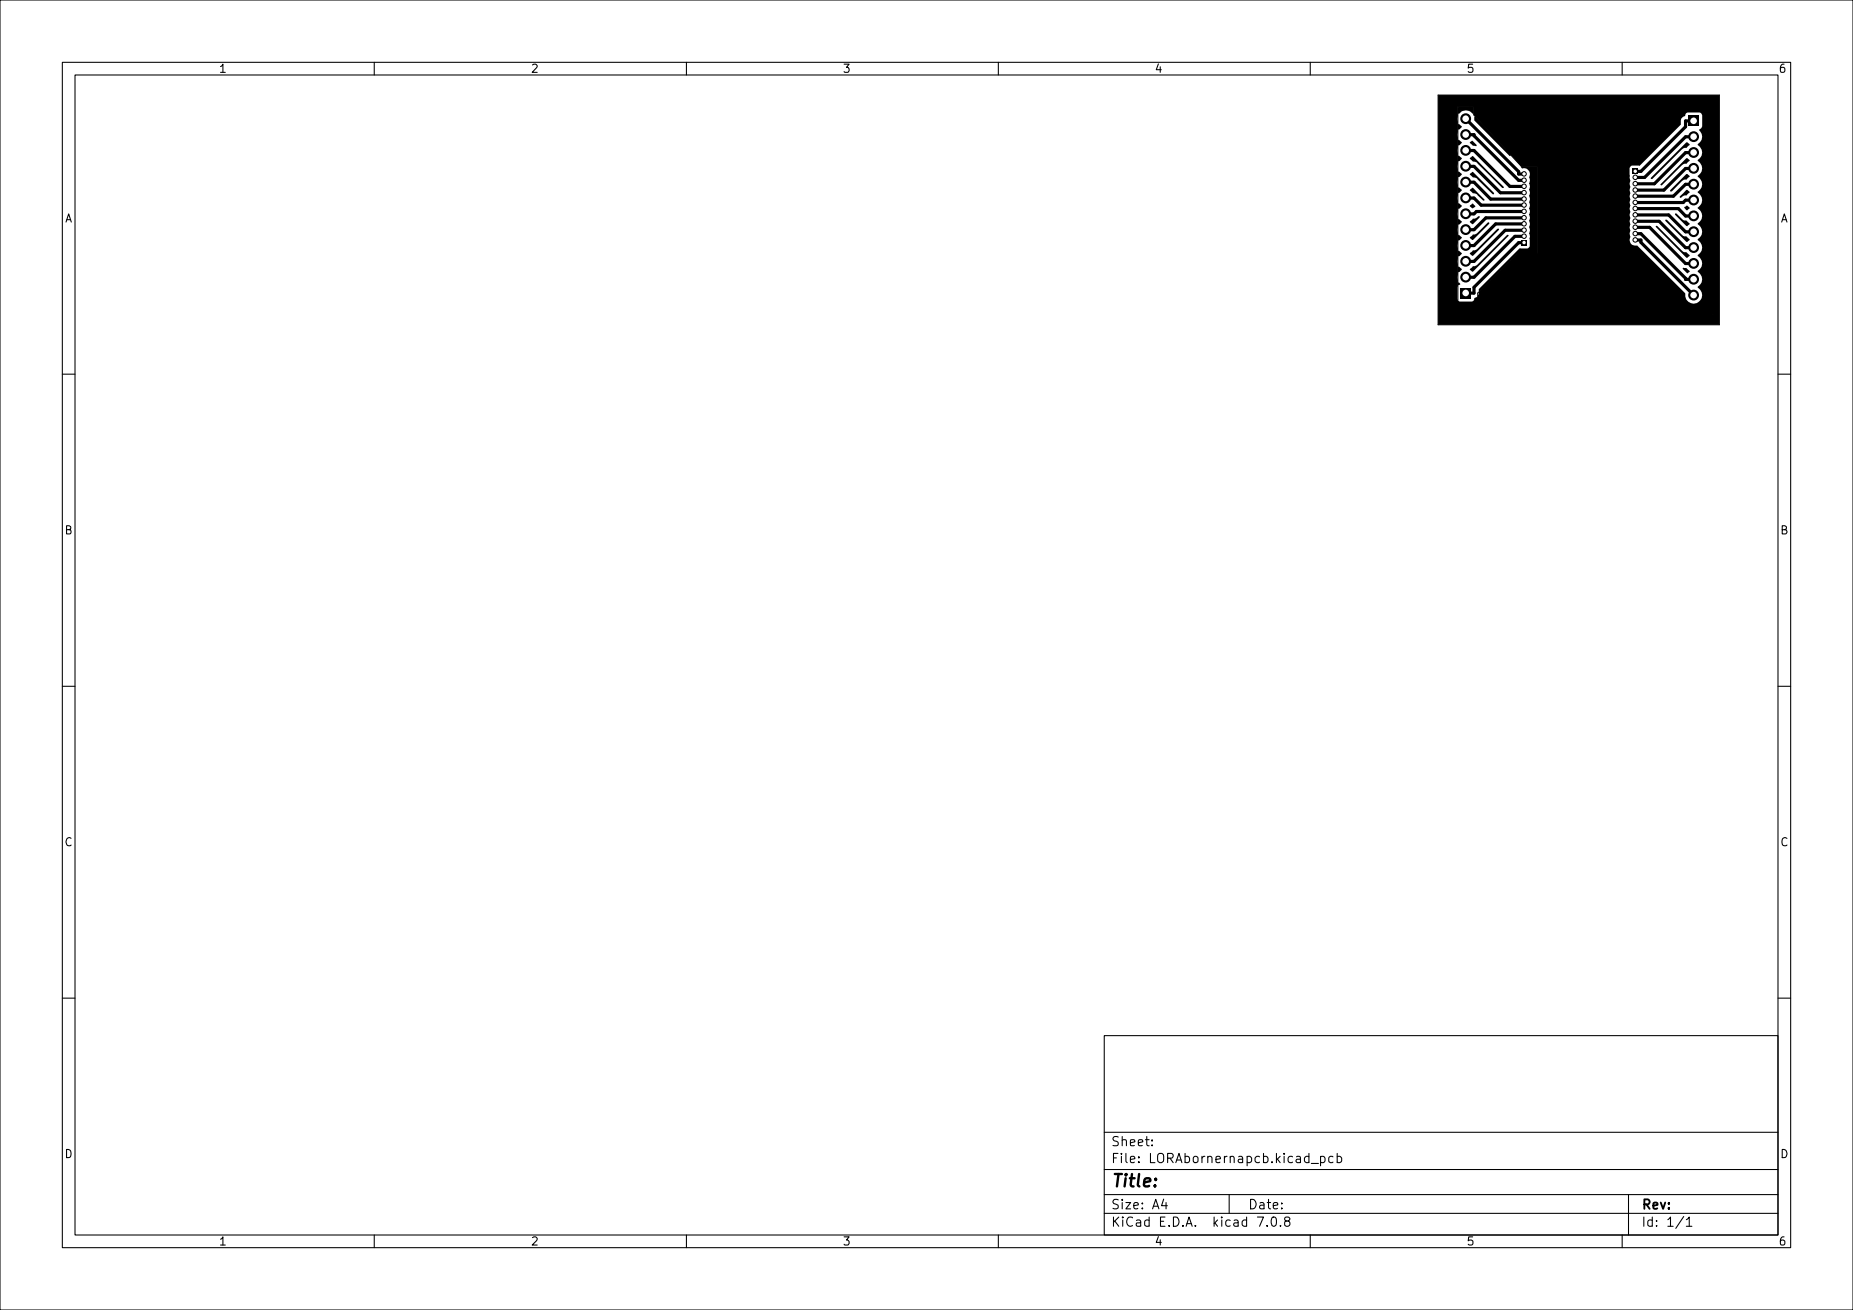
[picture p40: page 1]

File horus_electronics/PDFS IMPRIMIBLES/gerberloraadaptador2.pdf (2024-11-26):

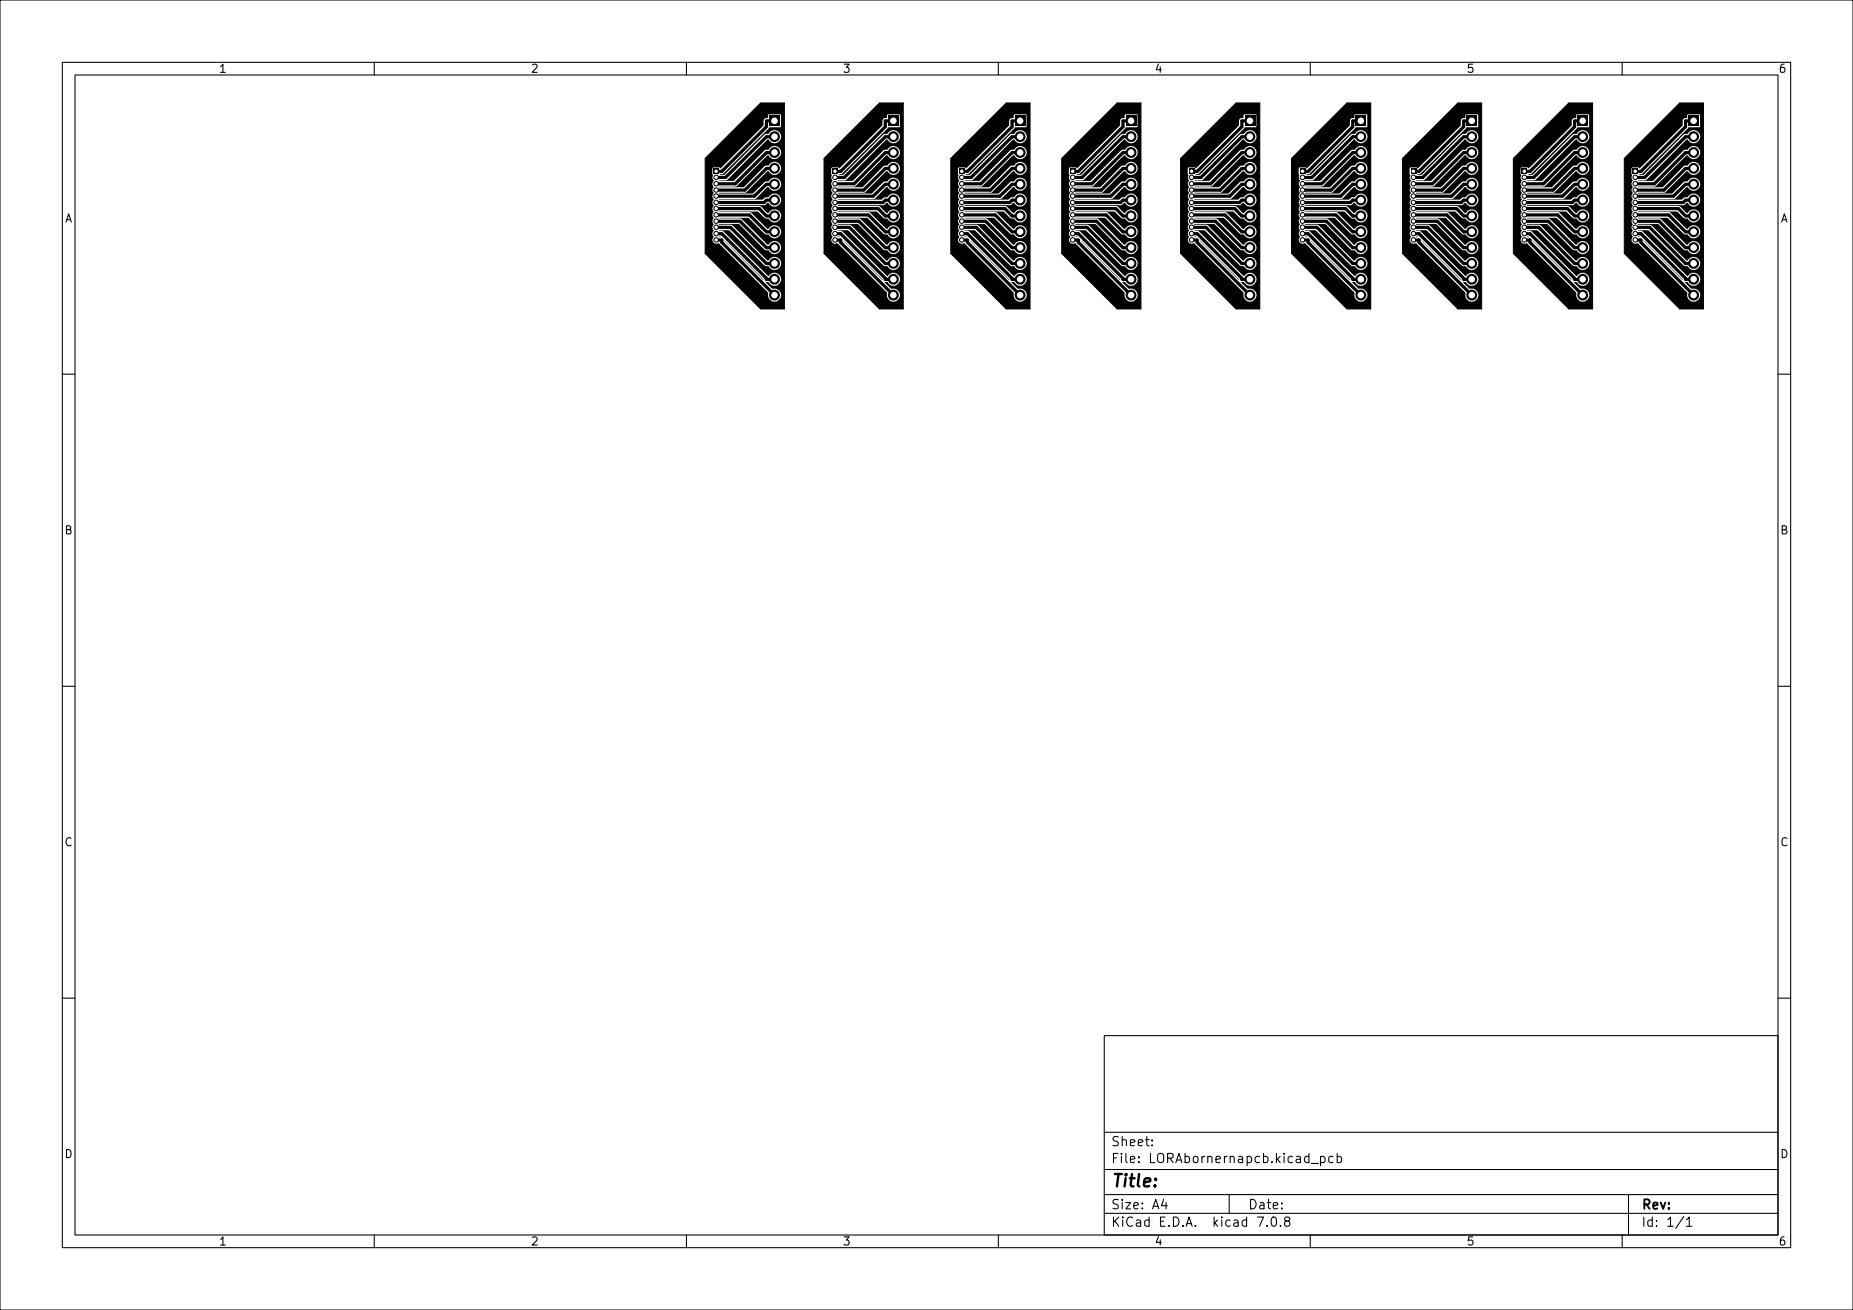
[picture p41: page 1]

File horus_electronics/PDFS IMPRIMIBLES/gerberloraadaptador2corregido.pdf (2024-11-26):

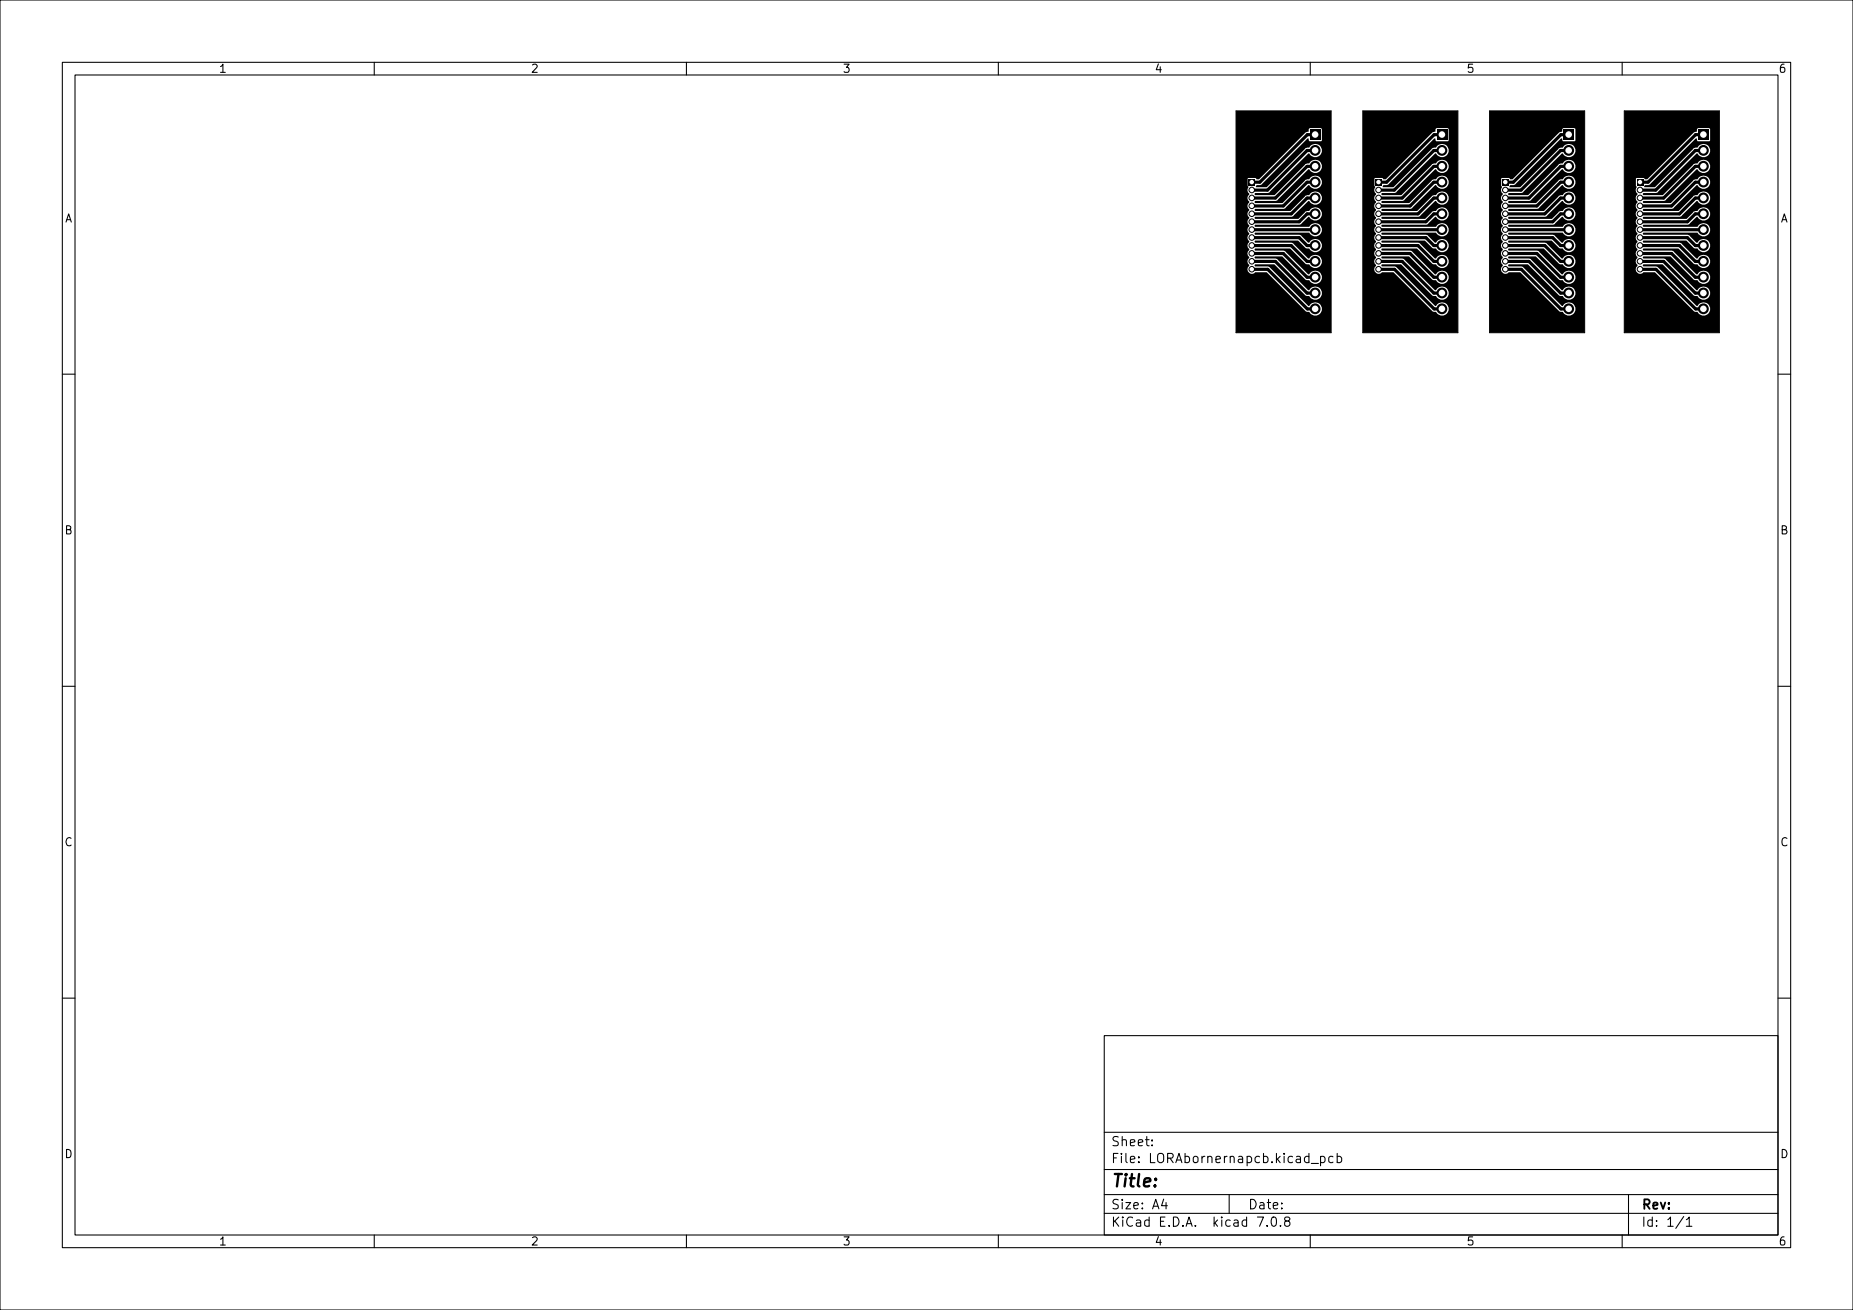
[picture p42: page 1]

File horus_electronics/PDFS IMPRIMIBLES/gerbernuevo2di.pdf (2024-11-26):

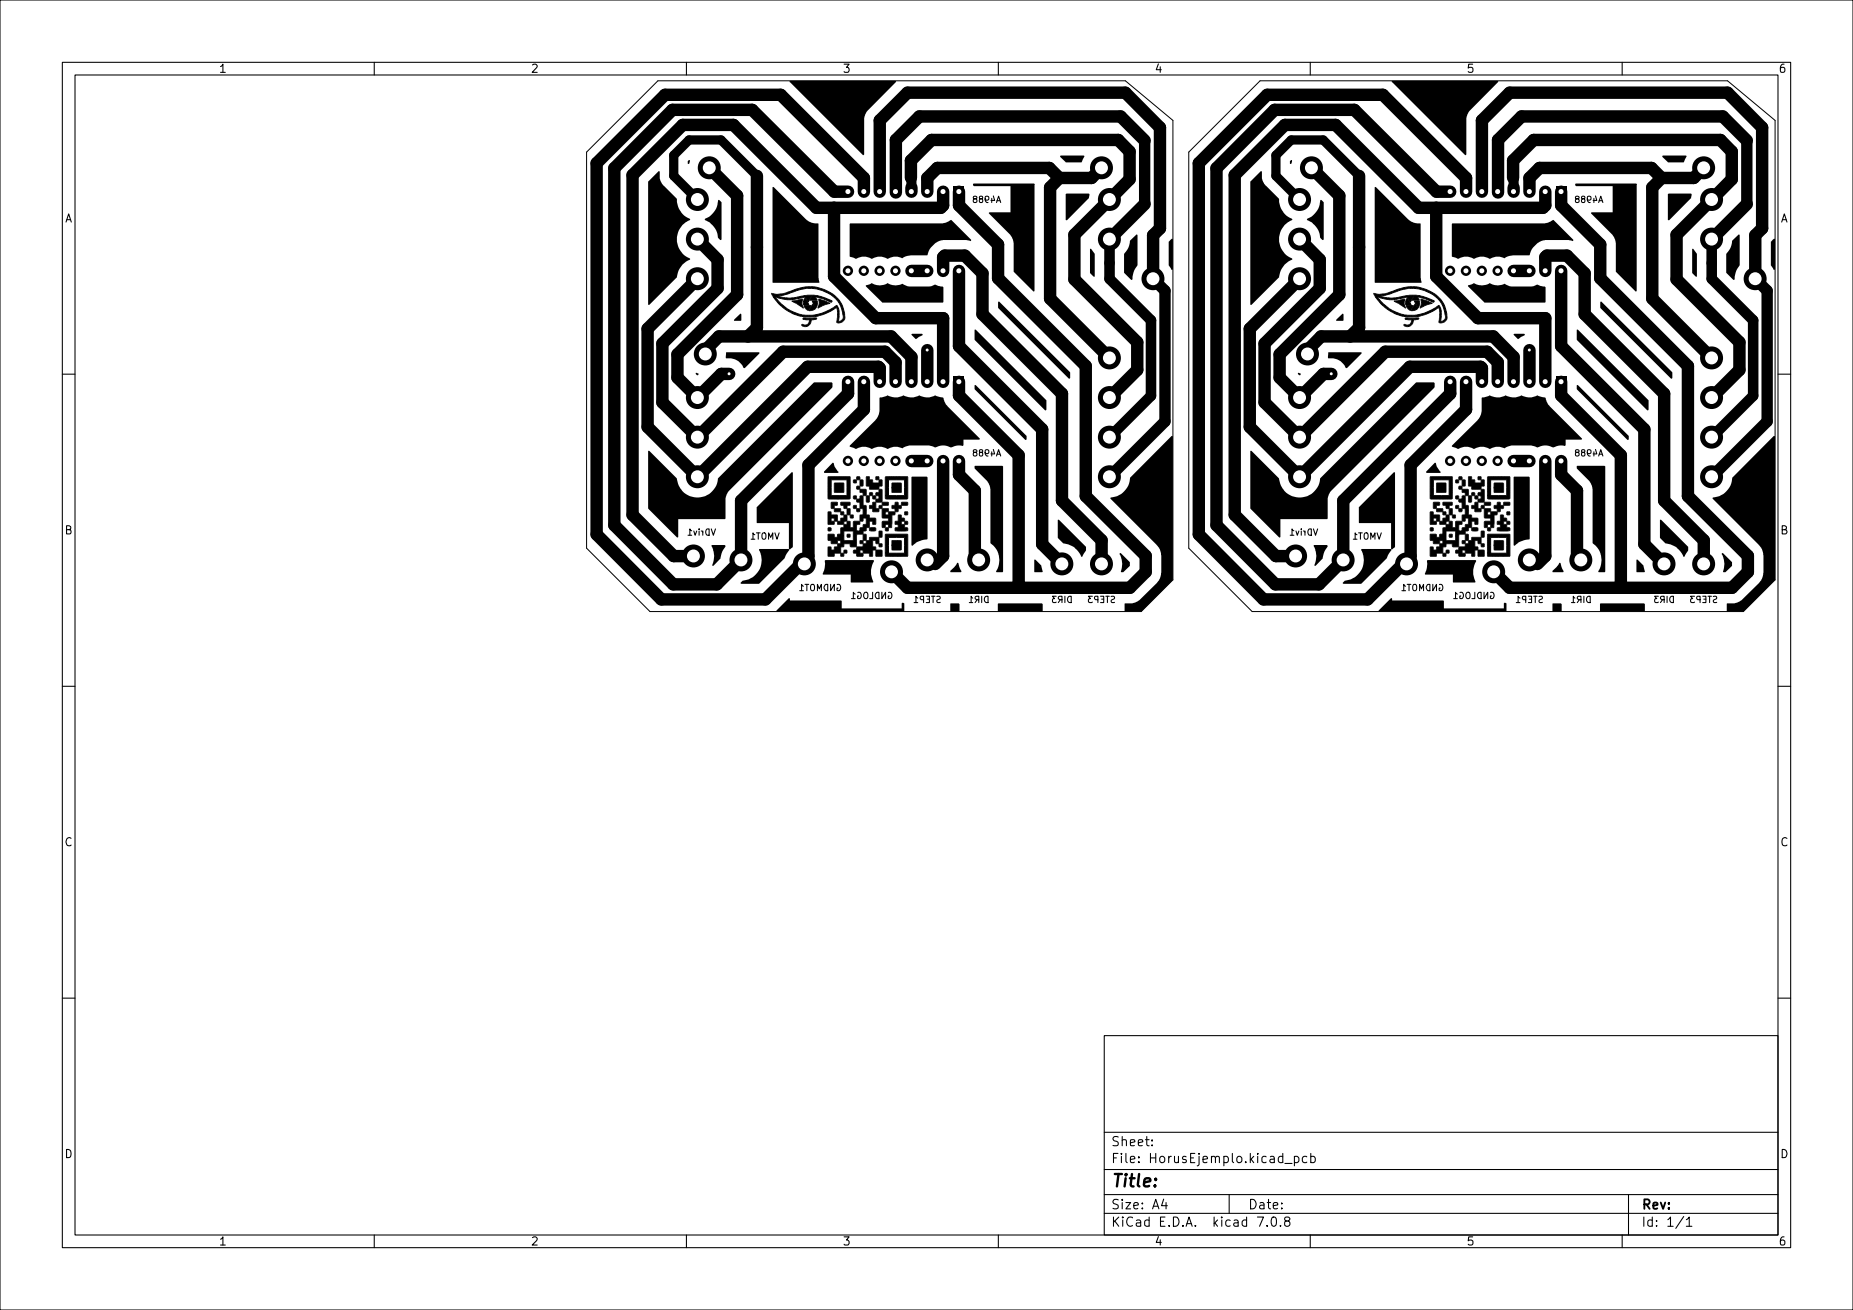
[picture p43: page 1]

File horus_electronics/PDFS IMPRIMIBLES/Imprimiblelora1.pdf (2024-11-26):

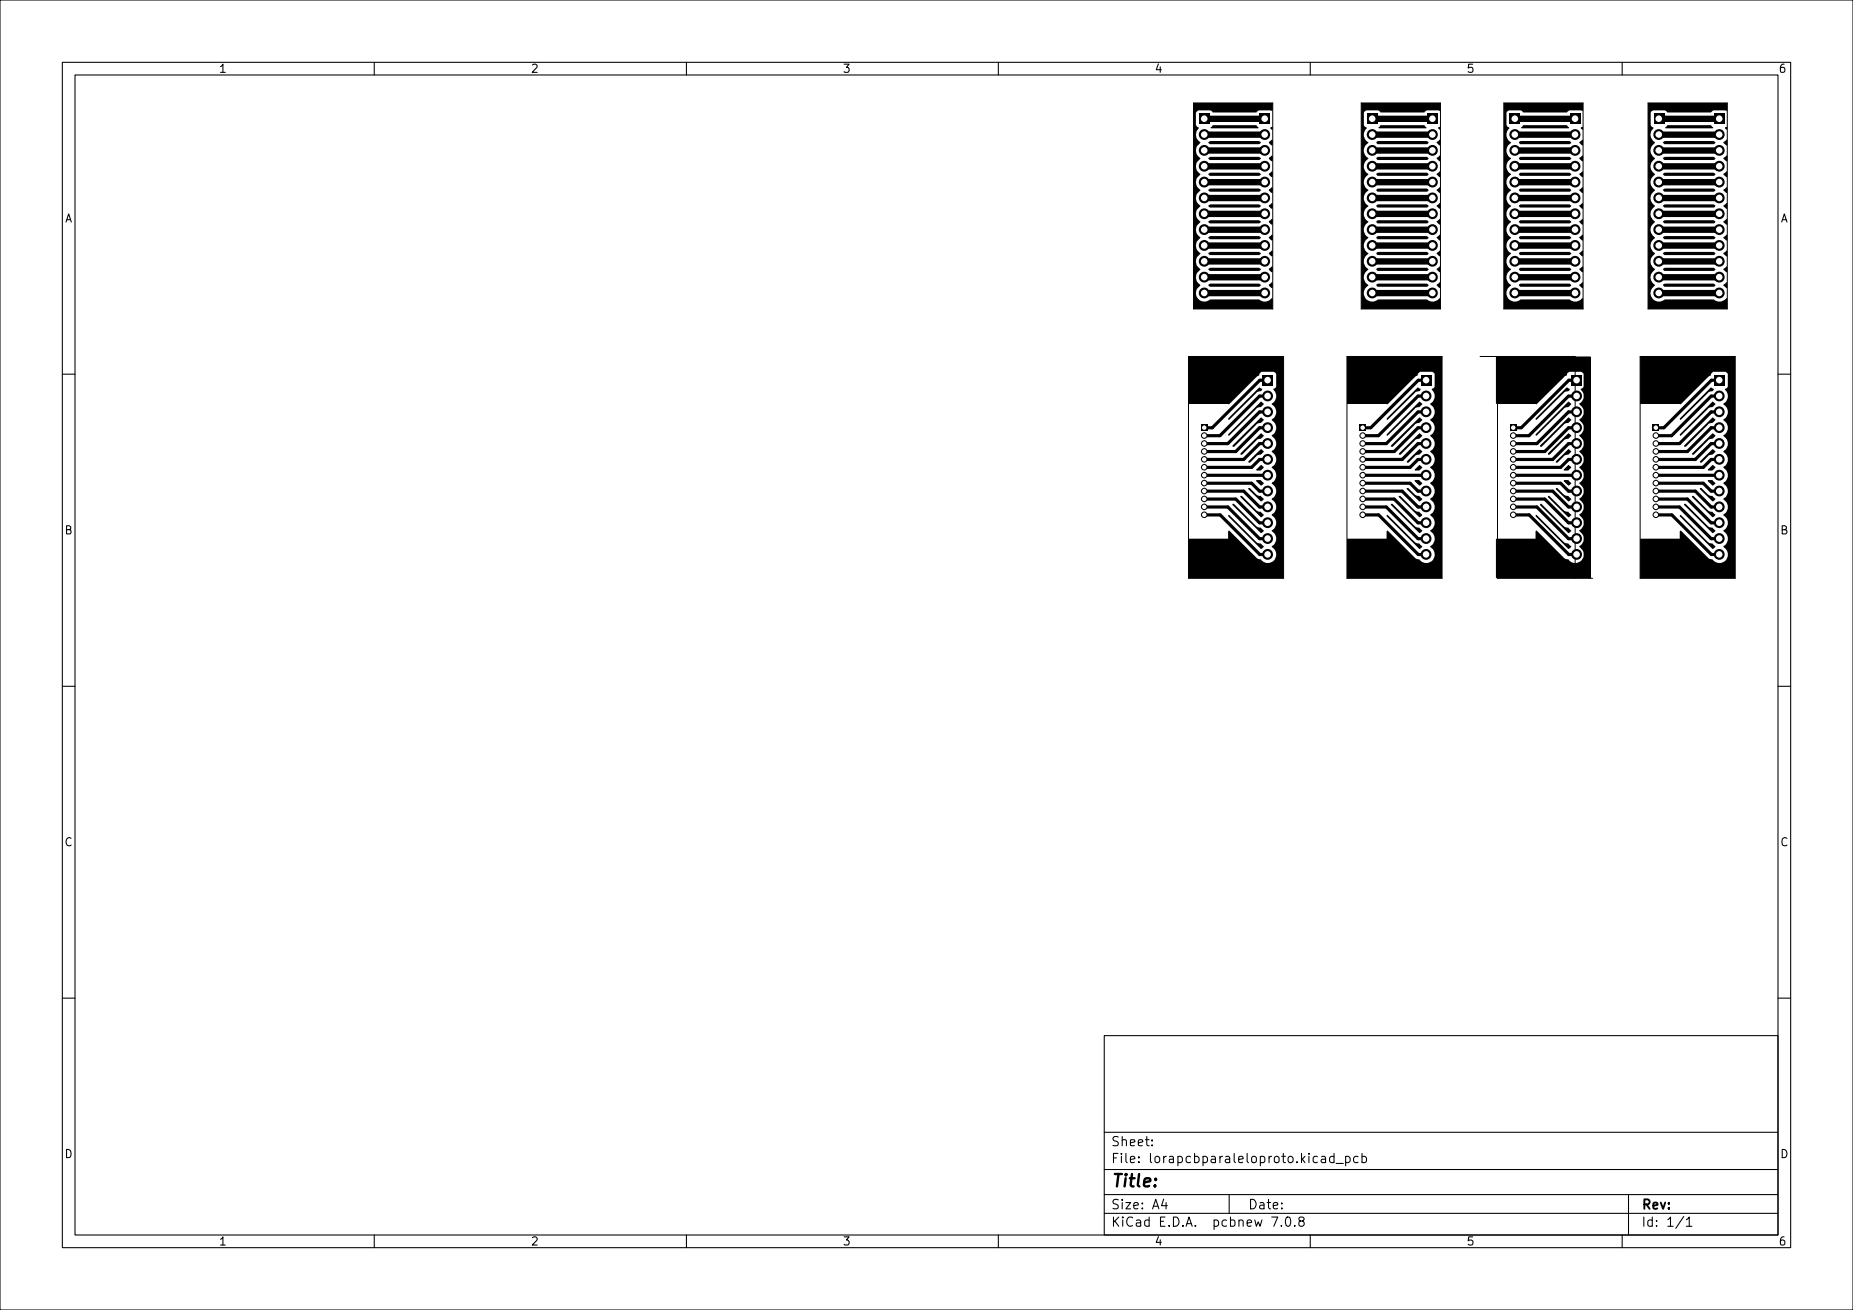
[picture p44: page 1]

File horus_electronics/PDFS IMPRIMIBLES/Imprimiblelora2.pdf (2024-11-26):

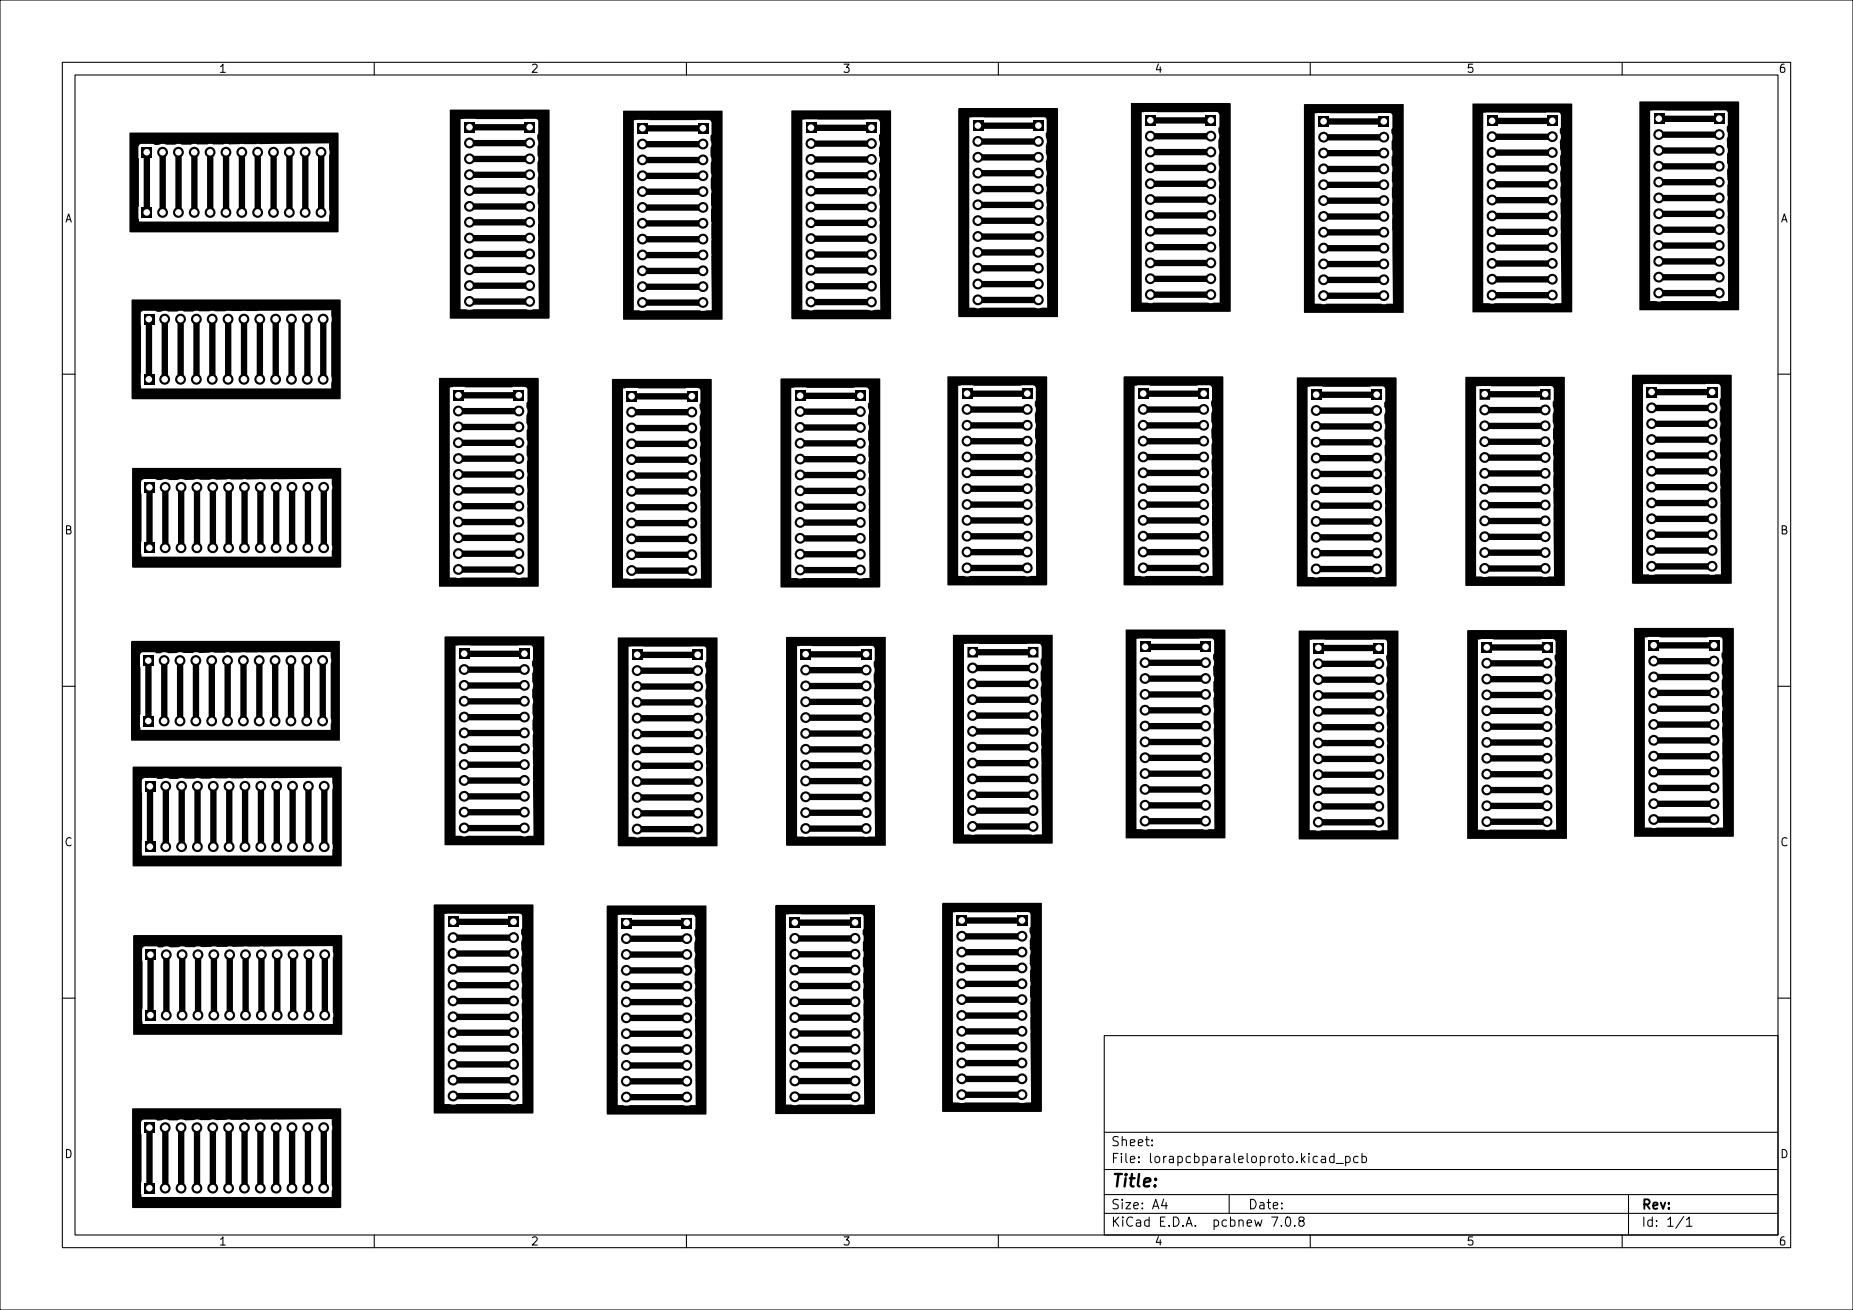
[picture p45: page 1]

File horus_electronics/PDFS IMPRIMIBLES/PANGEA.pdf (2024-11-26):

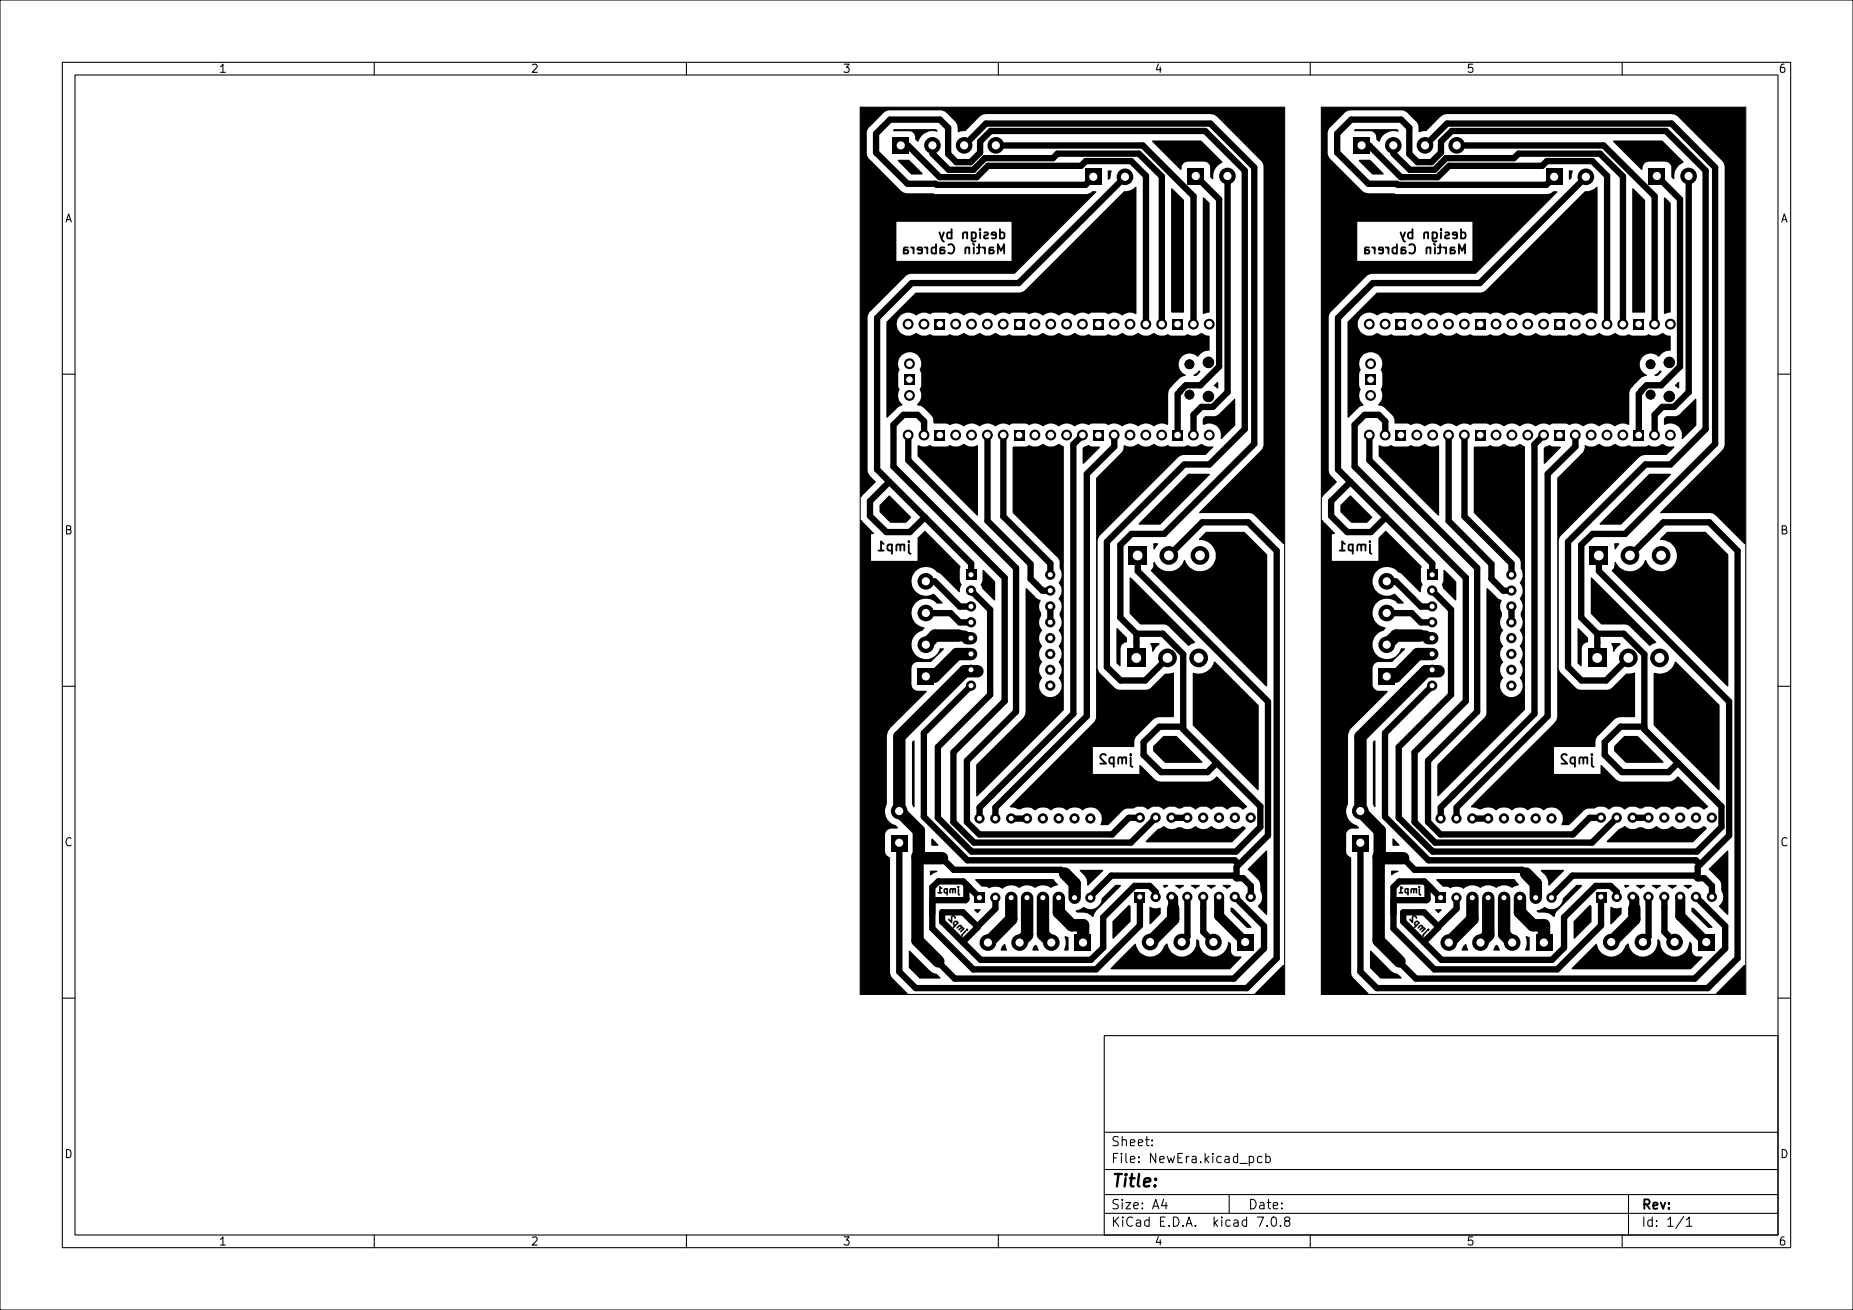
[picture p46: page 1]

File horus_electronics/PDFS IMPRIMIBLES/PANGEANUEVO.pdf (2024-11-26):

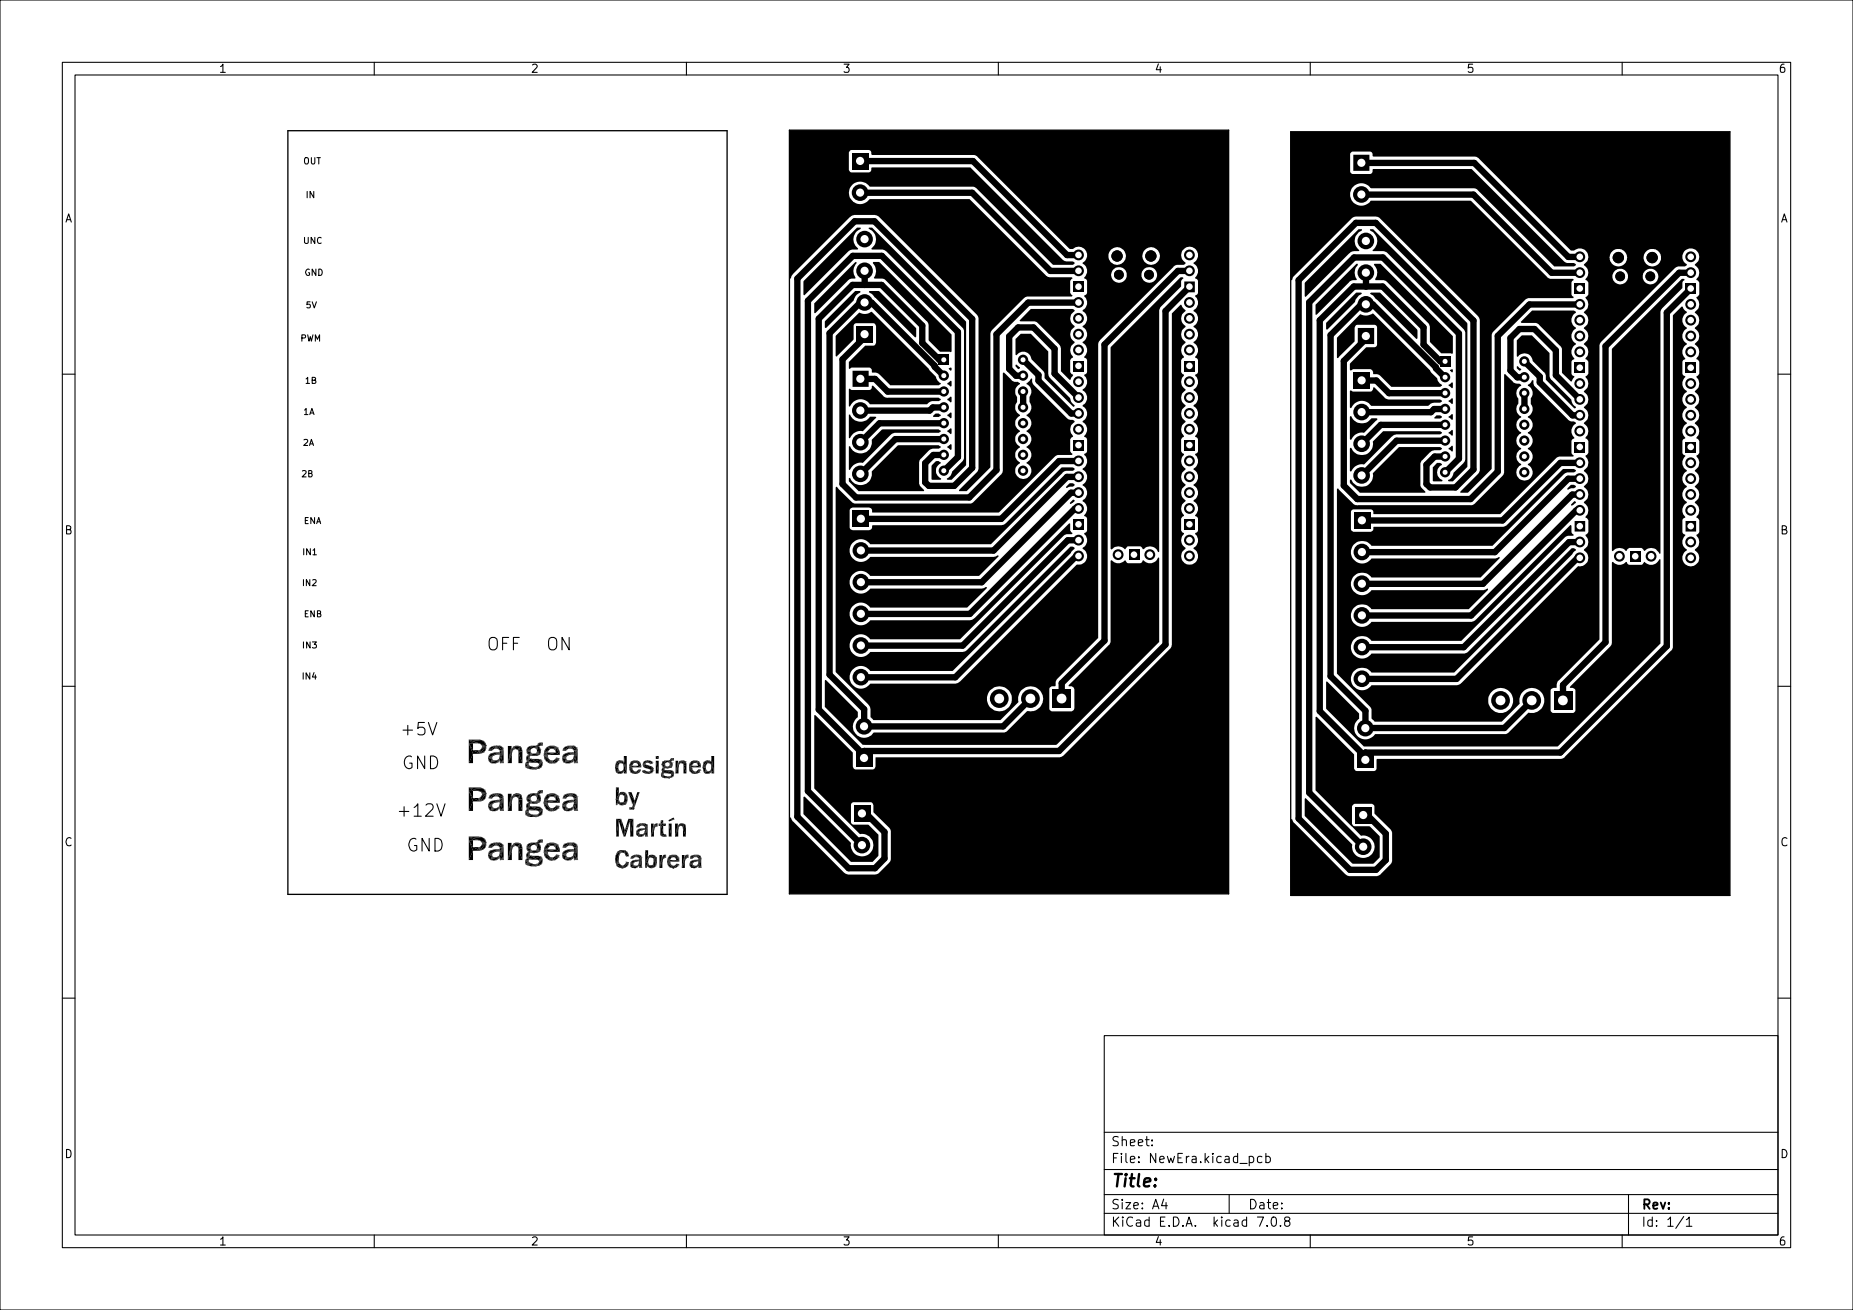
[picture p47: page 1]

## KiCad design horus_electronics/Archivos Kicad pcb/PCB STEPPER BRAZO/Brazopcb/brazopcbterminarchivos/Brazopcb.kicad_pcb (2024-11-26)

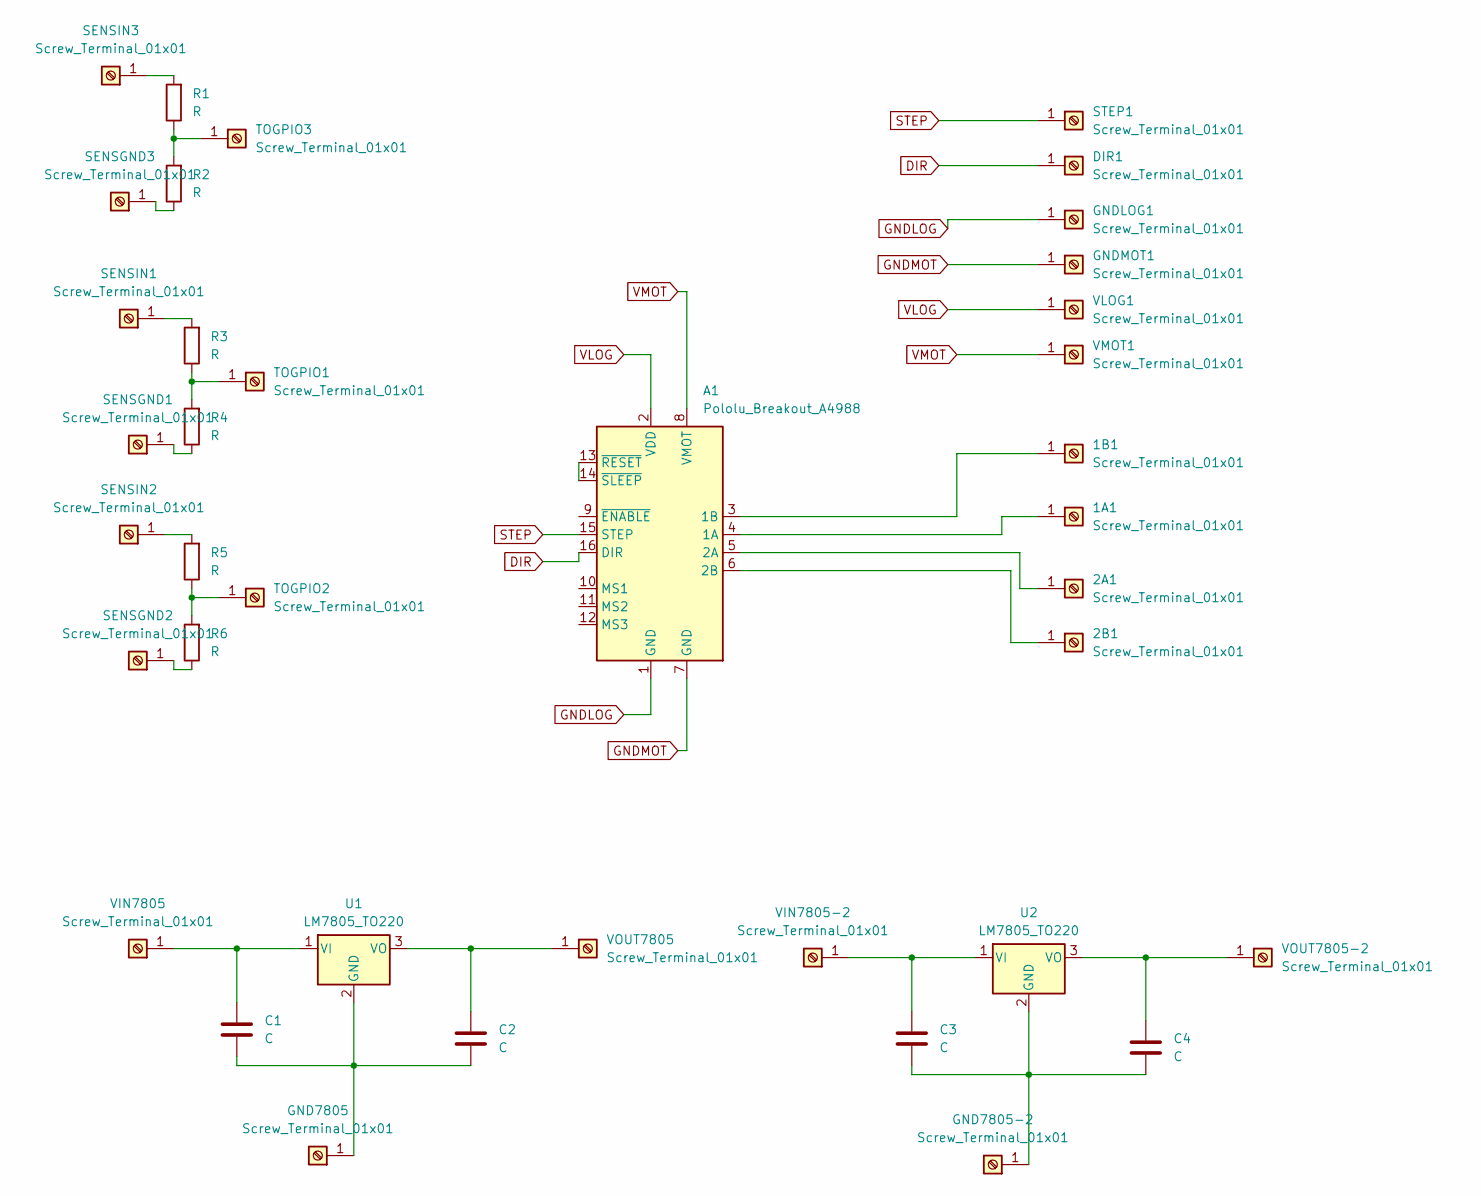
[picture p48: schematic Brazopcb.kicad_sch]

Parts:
1A1, 1B1, 2A1, 2B1: Screw_Terminal_01x01; Pin_D1.0mm_L10.0mm
A1: Pololu_Breakout_A4988; Pololu_Breakout-16_15.2x20.3mm
C1, C2, C3, C4: C; R_Axial_DIN0204_L3.6mm_D1.6mm_P5.08mm_Horizontal
DIR1: Screw_Terminal_01x01; Pin_D1.0mm_L10.0mm
GND7805, GND7805-2: Screw_Terminal_01x01; Pin_D1.0mm_L10.0mm
GNDLOG1: Screw_Terminal_01x01; Pin_D1.0mm_L10.0mm
GNDMOT1: Screw_Terminal_01x01; Pin_D1.0mm_L10.0mm
R1, R2, R3, R4, R5, R6: R; R_Axial_DIN0204_L3.6mm_D1.6mm_P7.62mm_Horizontal
SENSGND1, SENSGND2, SENSGND3: Screw_Terminal_01x01; Pin_D1.0mm_L10.0mm
SENSIN1, SENSIN2, SENSIN3: Screw_Terminal_01x01; Pin_D1.0mm_L10.0mm
STEP1: Screw_Terminal_01x01; Pin_D1.0mm_L10.0mm
TOGPIO1, TOGPIO2, TOGPIO3: Screw_Terminal_01x01; Pin_D1.0mm_L10.0mm
U1, U2: LM7805_TO220; TO-220-3_Vertical
VIN7805, VIN7805-2: Screw_Terminal_01x01; Pin_D1.0mm_L10.0mm
VLOG1: Screw_Terminal_01x01; Pin_D1.0mm_L10.0mm
VMOT1: Screw_Terminal_01x01; Pin_D1.0mm_L10.0mm
VOUT7805, VOUT7805-2: Screw_Terminal_01x01; Pin_D1.0mm_L10.0mm

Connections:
DIR: A1.16 (DIR), DIR1.1
GNDLOG: A1.1 (GND), GNDLOG1.1
GNDMOT: A1.7 (GND), GNDMOT1.1
unnamed: 1A1.1, A1.4 (1A)
unnamed: 1B1.1, A1.3 (1B)
unnamed: 2A1.1, A1.5 (2A)
unnamed: 2B1.1, A1.6 (2B)
unnamed: A1.13 (~RESET), A1.14 (~SLEEP)
unnamed: C3.2, C4.2, GND7805-2.1, U2.2 (GND)
unnamed: C1.2, C2.2, GND7805.1, U1.2 (GND)
unnamed: R4.1, SENSGND1.1
unnamed: R6.1, SENSGND2.1
unnamed: R2.1, SENSGND3.1
unnamed: R3.2, SENSIN1.1
unnamed: R5.2, SENSIN2.1
unnamed: R1.2, SENSIN3.1
unnamed: R3.1, R4.2, TOGPIO1.1
unnamed: R5.1, R6.2, TOGPIO2.1
unnamed: R1.1, R2.2, TOGPIO3.1
unnamed: C1.1, U1.1 (VI), VIN7805.1
unnamed: C2.1, U1.3 (VO), VOUT7805.1
unnamed: C3.1, U2.1 (VI), VIN7805-2.1
unnamed: C4.1, U2.3 (VO), VOUT7805-2.1
STEP: A1.15 (STEP), STEP1.1
VLOG: A1.2 (VDD), VLOG1.1
VMOT: A1.8 (VMOT), VMOT1.1

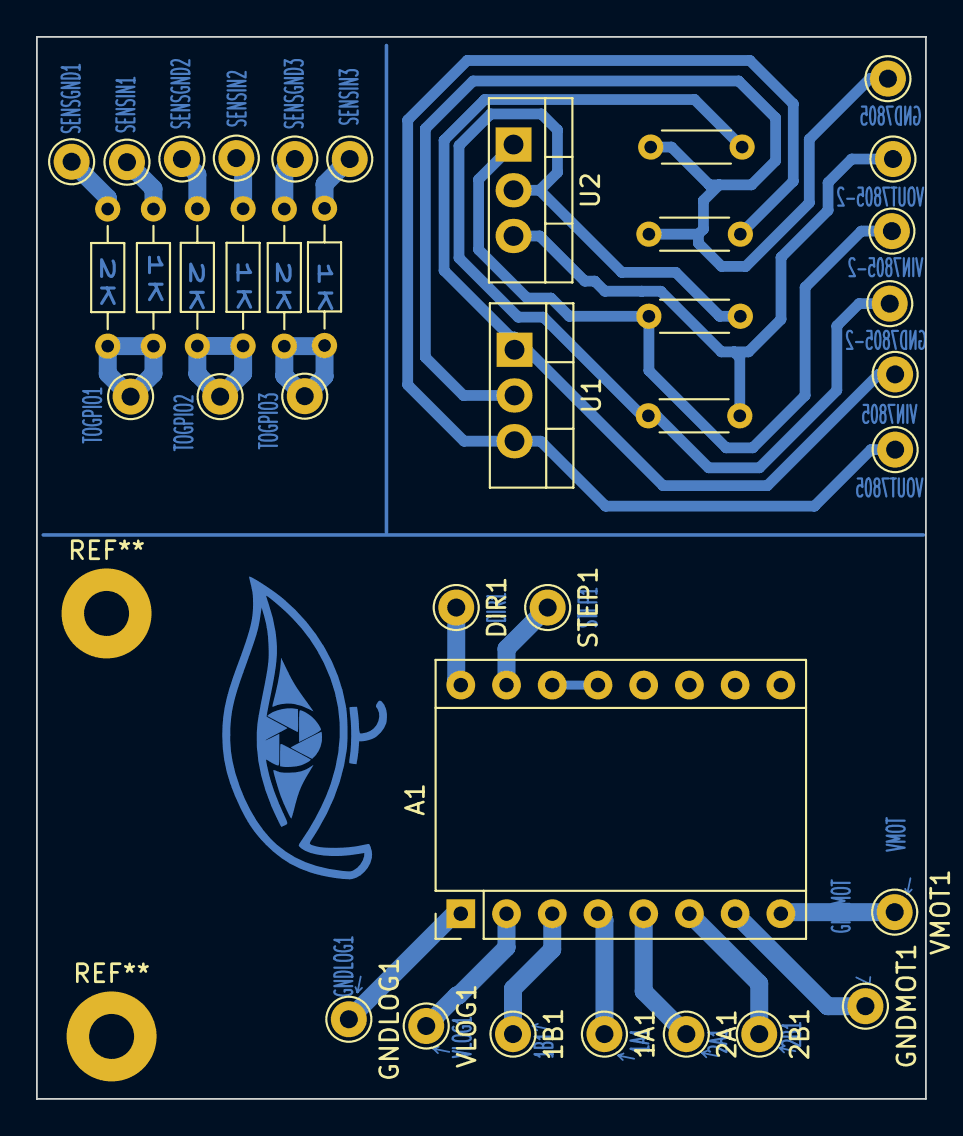
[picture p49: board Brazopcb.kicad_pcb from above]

Board: 2 copper layers, 49.4 x 59.0 mm, 38 parts (0 on the bottom side), 26 nets.

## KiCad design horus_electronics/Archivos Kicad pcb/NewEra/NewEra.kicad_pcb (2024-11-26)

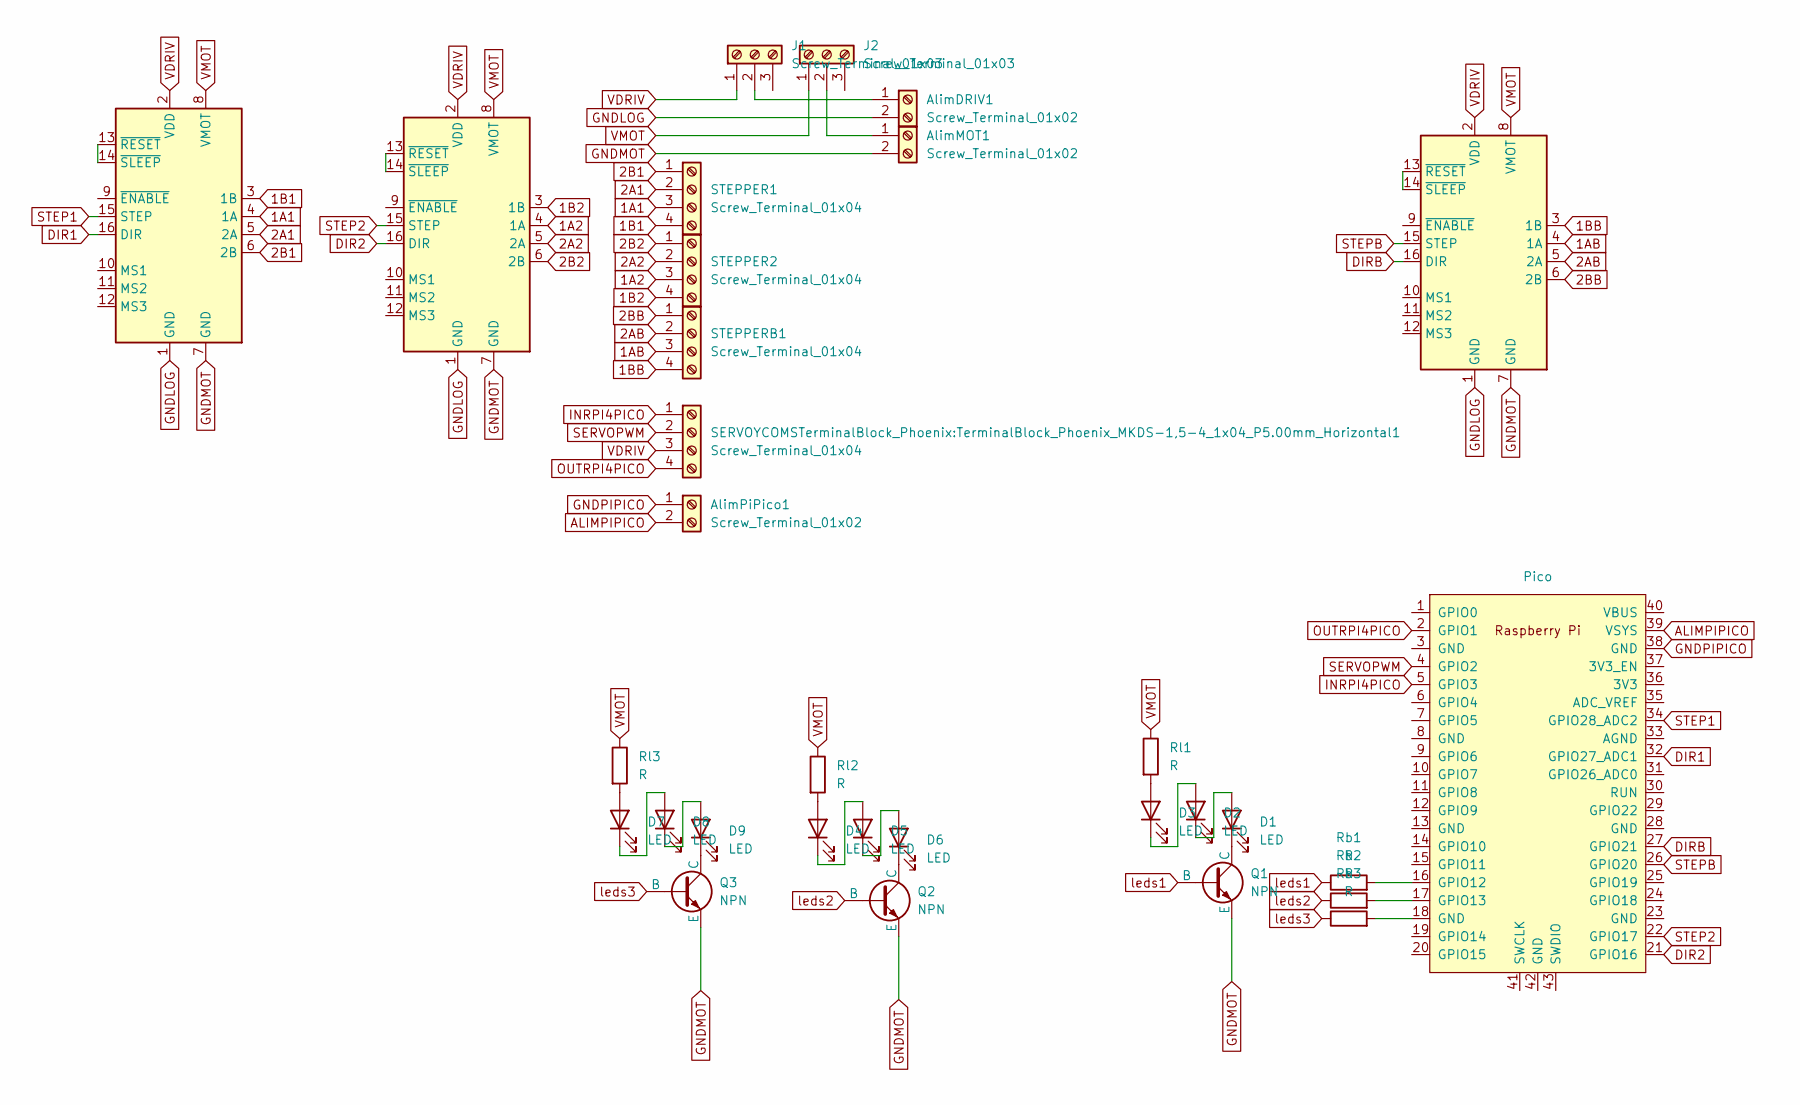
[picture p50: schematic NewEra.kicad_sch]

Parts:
A1, A2, A3: Pololu_Breakout_A4988; Pololu_Breakout-16_15.2x20.3mm
AlimDRIV1: Screw_Terminal_01x02; TerminalBlock_Phoenix_MKDS-1,5-2-5.08_1x02_P5.08mm_Horizont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
AlimMOT1: Screw_Terminal_01x02; TerminalBlock_Phoenix_MKDS-1,5-2-5.08_1x02_P5.08mm_Horizont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
AlimPiPico1: Screw_Terminal_01x02; TerminalBlock_Phoenix_MKDS-1,5-2-5.08_1x02_P5.08mm_Horizont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
D1, D2, D3, D4, D5, D6, D7, D8, D9: LED; LED_D1.8mm_W1.8mm_H2.4mm_Horizontal_O1.27mm_Z1.6mm
J1, J2: Screw_Terminal_01x03; Altech_AK300_1x03_P5.00mm_45-Degree
Q1, Q2, Q3: NPN; TO-92_HandSolder
Rb1, Rb2, Rb3: R; R_Axial_DIN0204_L3.6mm_D1.6mm_P5.08mm_Horizontal
Rl1, Rl2, Rl3: R; R_Axial_DIN0204_L3.6mm_D1.6mm_P5.08mm_Horizontal
SERVOYCOMSTerminalBlock_Phoenix:TerminalBlock_Phoenix_MKDS-1,5-4_1x04_P5.00mm_Horizontal1: Screw_Terminal_01x04; TerminalBlock_Phoenix_MKDS-1,5-4-5.08_1x04_P5.08mm_Horizont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
STEPPER1, STEPPER2: Screw_Terminal_01x04; TerminalBlock_Phoenix_MKDS-1,5-4-5.08_1x04_P5.08mm_Horizont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
STEPPERB1: Screw_Terminal_01x04; TerminalBlock_Phoenix_MKDS-1,5-4-5.08_1x04_P5.08mm_Horizont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
U1: Pico; RPi_Pico_SMD_TH

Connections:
1A1: A1.4 (1A), STEPPER1.3
1A2: A2.4 (1A), STEPPER2.3
1AB: A3.4 (1A), STEPPERB1.3
1B1: A1.3 (1B), STEPPER1.4
1B2: A2.3 (1B), STEPPER2.4
1BB: A3.3 (1B), STEPPERB1.4
2A1: A1.5 (2A), STEPPER1.2
2A2: A2.5 (2A), STEPPER2.2
2AB: A3.5 (2A), STEPPERB1.2
2B1: A1.6 (2B), STEPPER1.1
2B2: A2.6 (2B), STEPPER2.1
2BB: A3.6 (2B), STEPPERB1.1
ALIMPIPICO: AlimPiPico1.2, U1.39 (VSYS)
DIR1: A1.16 (DIR), U1.32 (GPIO27_ADC1)
DIR2: A2.16 (DIR), U1.21 (GPIO16)
DIRB: A3.16 (DIR), U1.27 (GPIO21)
GNDLOG: A1.1 (GND), A2.1 (GND), A3.1 (GND), AlimDRIV1.2
GNDMOT: A1.7 (GND), A2.7 (GND), A3.7 (GND), AlimMOT1.2, Q1.3 (E), Q2.3 (E), Q3.3 (E)
GNDPIPICO: AlimPiPico1.1, U1.38 (GND)
INRPI4PICO: SERVOYCOMSTerminalBlock_Phoenix:Termina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.1, U1.5 (GPIO3)
unnamed: A1.13 (~RESET), A1.14 (~SLEEP)
unnamed: A2.13 (~RESET), A2.14 (~SLEEP)
unnamed: A3.13 (~RESET), A3.14 (~SLEEP)
unnamed: AlimDRIV1.1, J1.2
unnamed: AlimMOT1.1, J2.2
unnamed: D1.2 (A), D2.1 (K)
unnamed: D1.1 (K), Q1.1 (C)
unnamed: D2.2 (A), D3.1 (K)
unnamed: D3.2 (A), Rl1.2
unnamed: D4.2 (A), Rl2.2
unnamed: D4.1 (K), D5.2 (A)
unnamed: D5.1 (K), D6.2 (A)
unnamed: D6.1 (K), Q2.1 (C)
unnamed: D7.2 (A), Rl3.2
unnamed: D7.1 (K), D8.2 (A)
unnamed: D8.1 (K), D9.2 (A)
unnamed: D9.1 (K), Q3.1 (C)
unnamed: Rb3.2, U1.18 (GND)
unnamed: Rb1.2, U1.16 (GPIO12)
unnamed: Rb2.2, U1.17 (GPIO13)
OUTRPI4PICO: SERVOYCOMSTerminalBlock_Phoenix:Termina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.4, U1.2 (GPIO1)
SERVOPWM: SERVOYCOMSTerminalBlock_Phoenix:Termina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.2, U1.4 (GPIO2)
STEP1: A1.15 (STEP), U1.34 (GPIO28_ADC2)
STEP2: A2.15 (STEP), U1.22 (GPIO17)
STEPB: A3.15 (STEP), U1.26 (GPIO20)
VDRIV: A1.2 (VDD), A2.2 (VDD), A3.2 (VDD), J1.1, SERVOYCOMSTerminalBlock_Phoenix:Termina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.3
VMOT: A1.8 (VMOT), A2.8 (VMOT), A3.8 (VMOT), J2.1, Rl1.1, Rl2.1, Rl3.1
leds1: Q1.2 (B), Rb1.1
leds2: Q2.2 (B), Rb2.1
leds3: Q3.2 (B), Rb3.1

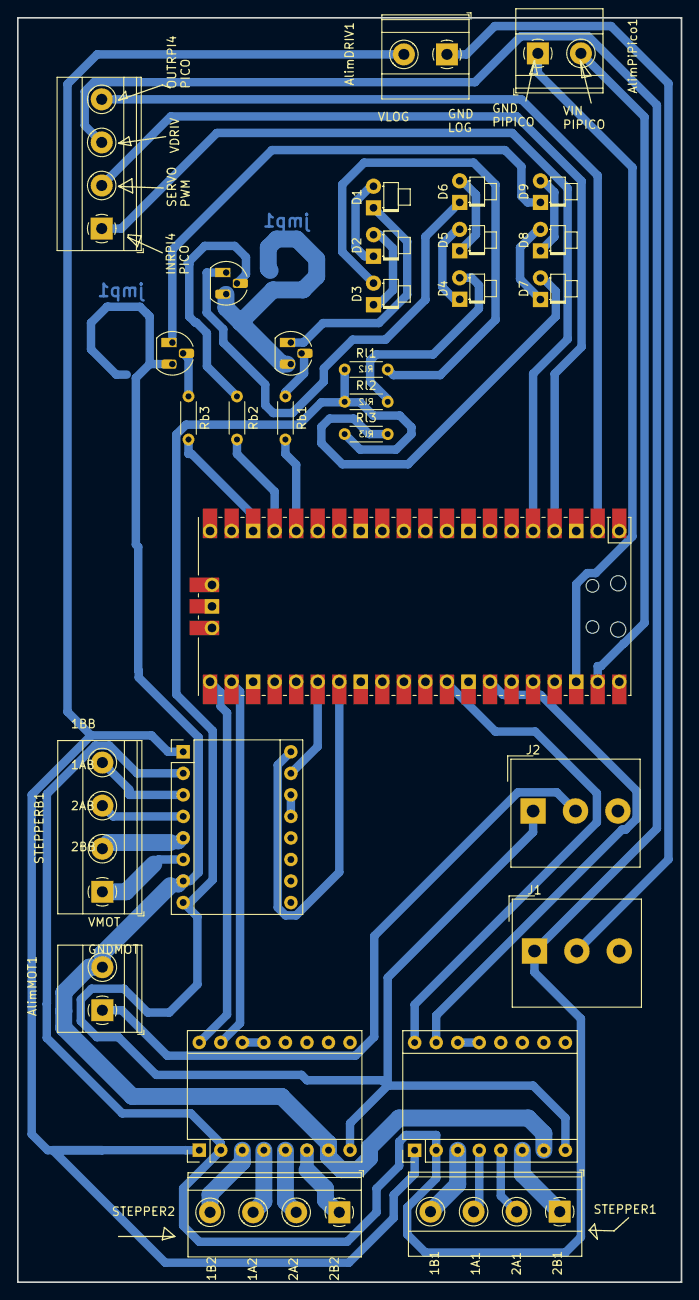
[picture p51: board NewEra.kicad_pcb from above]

Board: 2 copper layers, 78.3 x 149.1 mm, 31 parts (0 on the bottom side), 50 nets.

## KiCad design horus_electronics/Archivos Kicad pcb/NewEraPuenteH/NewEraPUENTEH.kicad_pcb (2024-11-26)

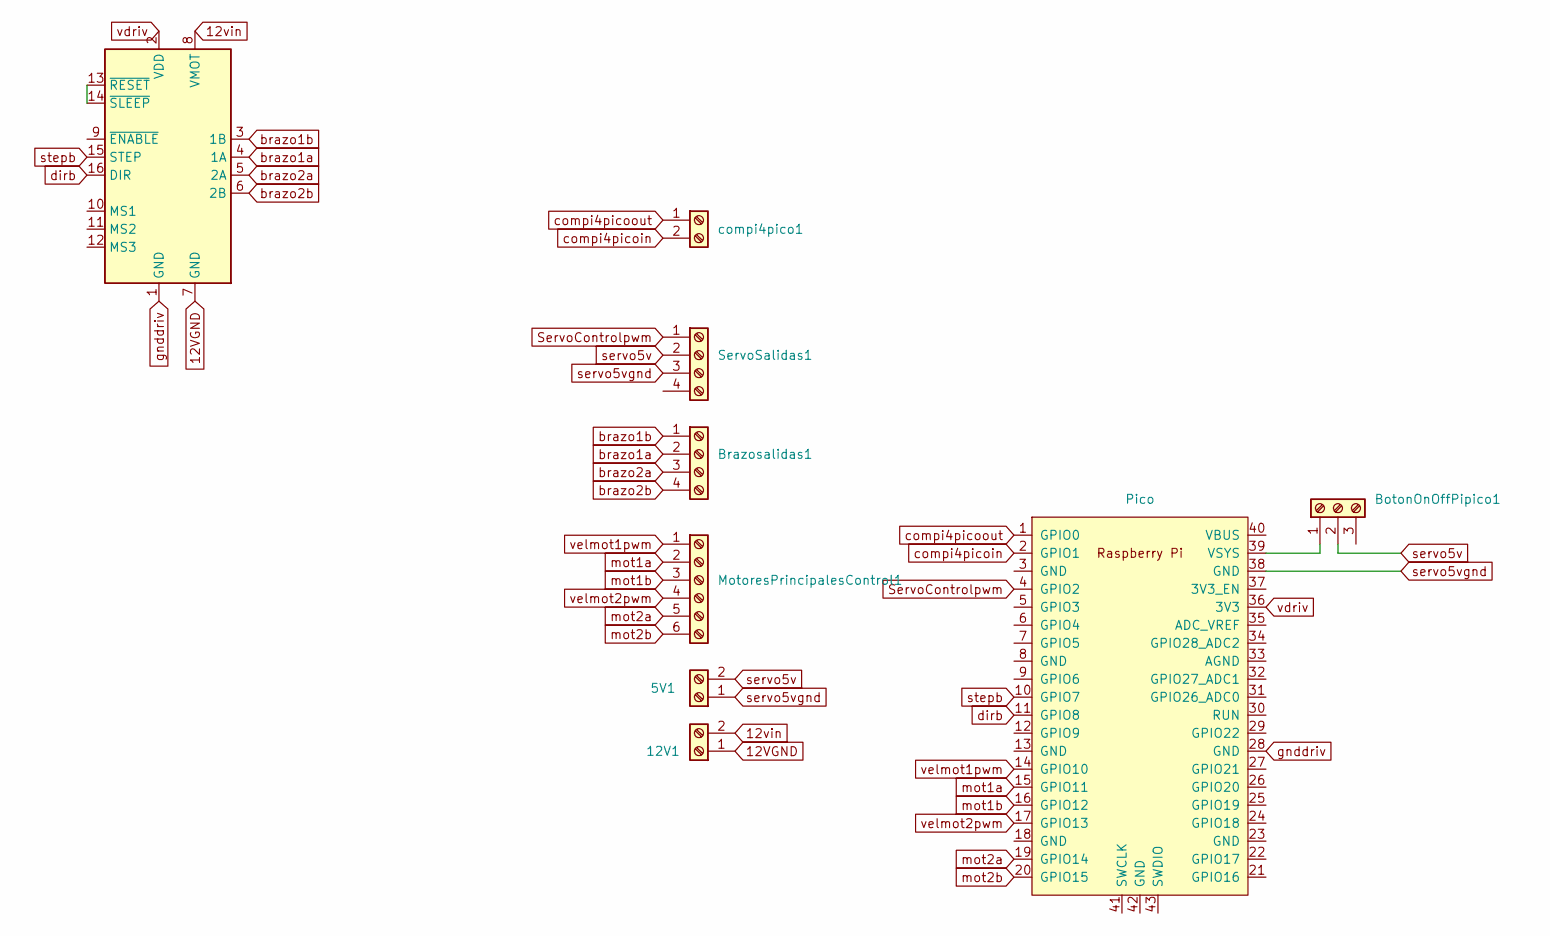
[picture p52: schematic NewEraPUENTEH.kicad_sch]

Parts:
5V1, 12V1: Screw_Terminal_01x02; TerminalBlock_Phoenix_MKDS-1,5-2-5.08_1x02_P5.08mm_Horizont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
A1: Pololu_Breakout_A4988; Pololu_Breakout-16_15.2x20.3mm
BotonOnOffPipico1: Screw_Terminal_01x03; Altech_AK300_1x03_P5.00mm_45-Degree
Brazosalidas1: Screw_Terminal_01x04; TerminalBlock_Phoenix_MKDS-1,5-4-5.08_1x04_P5.08mm_Horizont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
MotoresPrincipalesControl1: Screw_Terminal_01x06; TerminalBlock_Phoenix_MKDS-1,5-6-5.08_1x06_P5.08mm_Horizont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
ServoSalidas1: Screw_Terminal_01x04; TerminalBlock_Phoenix_MKDS-1,5-4-5.08_1x04_P5.08mm_Horizont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
U1: Pico; RPi_Pico_SMD_TH
compi4pico1: Screw_Terminal_01x02; TerminalBlock_Phoenix_MKDS-1,5-2-5.08_1x02_P5.08mm_Horizont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

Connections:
12VGND: 12V1.1, A1.7 (GND)
12vin: 12V1.2, A1.8 (VMOT)
unnamed: A1.13 (~RESET), A1.14 (~SLEEP)
unnamed: BotonOnOffPipico1.1, U1.39 (VSYS)
ServoControlpwm: ServoSalidas1.1, U1.4 (GPIO2)
brazo1a: A1.4 (1A), Brazosalidas1.2
brazo1b: A1.3 (1B), Brazosalidas1.1
brazo2a: A1.5 (2A), Brazosalidas1.3
brazo2b: A1.6 (2B), Brazosalidas1.4
compi4picoin: U1.2 (GPIO1), compi4pico1.2
compi4picoout: U1.1 (GPIO0), compi4pico1.1
dirb: A1.16 (DIR), U1.11 (GPIO8)
gnddriv: A1.1 (GND), U1.28 (GND)
mot1a: MotoresPrincipalesControl1.2, U1.15 (GPIO11)
mot1b: MotoresPrincipalesControl1.3, U1.16 (GPIO12)
mot2a: MotoresPrincipalesControl1.5, U1.19 (GPIO14)
mot2b: MotoresPrincipalesControl1.6, U1.20 (GPIO15)
servo5v: 5V1.2, BotonOnOffPipico1.2, ServoSalidas1.2
servo5vgnd: 5V1.1, ServoSalidas1.3, U1.38 (GND)
stepb: A1.15 (STEP), U1.10 (GPIO7)
vdriv: A1.2 (VDD), U1.36 (3V3)
velmot1pwm: MotoresPrincipalesControl1.1, U1.14 (GPIO10)
velmot2pwm: MotoresPrincipalesControl1.4, U1.17 (GPIO13)

Board: 2 copper layers, 9 parts (0 on the bottom side), 23 nets, no tracks yet.

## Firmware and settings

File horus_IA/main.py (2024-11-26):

from LoRaRF import SX127x
import RPi.GPIO as GPIO
import time
import os

## Seteo configuracion del Lora ##
LoRa = SX127x()
LoRa.begin()

# Set frequency to 433 Mhz
LoRa.setFrequency(433000000)
# set spreading factor 8, bandwidth 125 kHz, coding rate 4/5, and low data rate optimization off
LoRa.setLoRaModulation(7, 125000, 5, False)
# set explicit header mode, preamble length 12, payload length 15, CRC on and no invert IQ operation
LoRa.setLoRaPacket(LoRa.HEADER_EXPLICIT, 12, 2, True, False)

## Configuracion del robot (interna) ##

pin_seguridad = "R1"
id_robot = "1"

mensaje = ""

class Robot():
    def __init__(self, ID, Pin):
        self.id = ID
        self.pin = Pin
        
    def run(self):
        
        verificacion = False
        
        #programa principal aca
        while verificacion != True:
            mensaje = receptor()
            if mensaje == "%":
                mensaje = receptor()
                if mensaje == "R":
                    mensaje = receptor()
                    if mensaje == "R":
                        mensaje = receptor()
                        if mensaje == "1":
                            verificacion = True
        
        print ("verificado")
        
        coords = coordenadas()
        bate = bateria()
        
        mensaje = "{type: confirm, type: robot_id:1, battery: ", bate, "time_left: 20hr, coordenadas: [0,0]}"
        transmisor(mensaje)
        
        ruta = receptor() # area: [(x,y),(x,y),(x,y),(x,y)]
        
        ## Programa de prueba wink wink ##
        
        ruta = [0,0, 0,10, 10,10, 10,0]
        
        ## Falta trampa de feromona ##
        
        # 1 grado de latitud o longitud equivale a 111.319m
        
        metros = (ruta[3] - ruta[0]) * 111.319

        print (metros)
        
        recorrido = 0
        
        while recorrido < metros:
            
            # pongo en marcha motores durante 1 metro
            time.sleep(1)
            
            #paro los motores
            
            # estiro el brazo 20 cm
            
            os.system ("wget -P /home/horus/Desktop/New/yolov5/data/images http://192.168.221.56:8080/photo.jpg")
            time.sleep(1)
            os.system ("python detect.py --weights orugasmodelo.pt --img 640 --conf 0.25 --source data/images")
            time.sleep(30) #se duerme por 30 segundos
            
            with open ("orugas.txt") as f:
                num_det = json.load(f)
            
            mensaje = "Deteccion: "
            transmisor(mensaje)
            mensaje = str(num_det)
            transmisor(mensaje)
            recorrido = recorrido + 1


        
            
    
    def receptor(self):
        # Request for receiving new LoRa packet
        LoRa.request()
        # Wait for incoming LoRa packet
        LoRa.wait()
        # Put received packet to message and counter variable
        # read() and available() method must be called after request() or listen() method
        message = ""
        # available() method return remaining received payload length and will decrement each read() or get() method called
        while LoRa.available() > 1 :
            message += chr(LoRa.read()) 
        counter = LoRa.read()

        # Print received message and counter in serial
        print(chr(counter))

        # Print packet/signal status including RSSI, SNR, and signalRSSI
        print("Packet status: RSSI = {0:0.2f} dBm | SNR = {1:0.2f} dB".format(LoRa.packetRssi(), LoRa.snr()))
        time.sleep(0.5)
        # Show received status in case CRC or header error occur
        status = LoRa.status()
        if status == LoRa.STATUS_CRC_ERR : print("CRC error")
        elif status == LoRa.STATUS_HEADER_ERR : print("Packet header error")
        
        return counter
    
    def transmisor (self, mensaje):
        message = "HeLoRa World!\0"
        messageList = list(message)
        for i in range(len(messageList)) : messageList[i] = ord(messageList[i])
        counter = 0
        
        # Transmit message and counter
        # write() method must be placed between beginPacket() and endPacket()
        LoRa.beginPacket()
        LoRa.write(messageList, len(messageList))
        LoRa.write([counter], 1)
        LoRa.endPacket()

        # Print message and counter
        print(f"{message}  {counter}")

        # Wait until modulation process for transmitting packet finish
        LoRa.wait()

        # Print transmit time and data rate
        print("Transmit time: {0:0.2f} ms | Data rate: {1:0.2f} byte/s".format(LoRa.transmitTime(), LoRa.dataRate()))

        # Don't load RF module with continous transmit
        time.sleep(5)
        counter = (counter + 1) % 256
    
    def codificador(self):
        pass
    
    def decodificador(self):
        pass
        
    def coordenadas(self):
        pass
    
    def bateria(self, bateria):
        self.bateria = bateria
        self.bateria = "100%"
        
        return self.bateria
        
    def ultrasonido(self):
        pass
    

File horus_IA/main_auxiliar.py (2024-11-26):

#from LoRaRF import SX127x
#import RPi.GPIO as GPIO
import time
import os
import json
import cv2

## Seteo configuracion del Lora ##
#LoRa = SX127x()
#LoRa.begin()

# Set frequency to 433 Mhz
#LoRa.setFrequency(433000000)
# set spreading factor 8, bandwidth 125 kHz, coding rate 4/5, and low data rate optimization off
#LoRa.setLoRaModulation(7, 125000, 5, False)
# set explicit header mode, preamble length 12, payload length 15, CRC on and no invert IQ operation
#LoRa.setLoRaPacket(LoRa.HEADER_EXPLICIT, 12, 2, True, False)

## Configuracion del robot (interna) ##


#camera_index is the video device number of the camera 

# Declara una variable y le asigna la camara numero 0 (Si hay mas camaras, se usa 1,2,3 respectivamente)


pin_seguridad = "R1"
id_robot = "1"

mensaje = ""

class Robot():
    def __init__(self, ID, Pin):
        self.id = ID
        self.pin = Pin
        
    def run(self):

        verificacion = False

        logs = []

        ubicacion = [51.496756, -0.138503] #ACA USAR FUNCION DEL GPS
        
        # Verificacion de datos mediante pendrive 
        dictionary =  {
        "robot_id": self.id,
        "location": ubicacion,
        "battery": 75,
        "time_left": "03:30:29", 
        "last_log": "31-01-2024"
        }

        logs.append(dictionary)
 
        # Writing to sample.json
        with open("txsample.json", "w") as outfile:
            json.dump(logs, outfile)
            #outfile.write(logs)
        
        # lee el archivo pendrive para saber la ruta
        
        with open('rxsample.json', 'r') as openfile:
 
            # Reading from json file
            lecturarx = json.load(openfile)
 
        print(lecturarx['polygon_coordinates']) 

        ruta = lecturarx["polygon_coordinates"]
        punto_de_inicio = lecturarx["starting_point"]
        
        if punto_de_inicio == ubicacion :
            verificacion = True
            print ("verificado, iniciando ruta ...")
        
        ## Falta trampa de feromona ##
        
        # 1 grado de latitud o longitud equivale a 111.319m
        
        etapa_1 = ruta[1]

        metros = ((ubicacion[0] - etapa_1[0])* 10000)

        print (metros)
        
        recorrido = 0
        extr = 0
        

        while verificacion:
            
            cap = cv2.VideoCapture(0)
            i = 0
            
            # pongo en marcha motores durante 1 metro
            
            #paro los motores
            
            # estiro el brazo 20 cm
            
            while i < 5:
                ret, capturador = cap.read()
                # El ret regresa un booleano de si funciona la camara, y el frame actual
                cv2.imshow('nombre', capturador)
                key  = cv2.waitKey(1) & 0xFF

                print ("tomando captura")
    
                nombre = "fotosoja" + str(extr) #toma el momento de la captura en tiempo
        
                cv2.imwrite("/home/horus/Desktop/yolov5/data/images/ "  + nombre +  ".jpg" , capturador)
                # guarda la captura en la carpeta asignada, la carpeta se cambia segun la computadora y donde quieras ubicar el archivo
                # NOTA: a futuro usar tkinter para abrir una pantalla que le pida al usuario donde quiere poner las imagenes
                # A la direccion se le agrega una \ y un espacio, sino no funciona.
    
                extr = extr + 1
                print (nombre)
                time.sleep(2)
                
                

                i = i + 1
    

            cap.release()
            # release porque deja que otro programa pueda usar la camara mientras no se corra el while true
            cv2.destroyAllWindows()

            # Se cierra la camara con la letra Q

            #os.system ("wget -P /home/horus/Desktop/New/yolov5/data/images http://192.168.221.56:8080/photo.jpg")
            os.system ("python detect.py --weights orugasmodelo.pt --img 640 --conf 0.25 --source data/images")

           
            with open('orugas.json', 'r') as openfile:
                orugasdict = json.load(openfile)
            
            num_det = orugasdict['num_det']

            deteccion =  {
                "robot_id": 1,
                "plague_type": "oruga",
                "plague_detection": num_det,
                "pheromone_trap": False,
                "image_id": 12311,
                "probability": 100,
                "date": "31-01-2024",
                "time": "16:42",
                "coordinates": [51.505, -0.09]
                }
            
            logs.append(deteccion)
 
            # Writing to sample.json
            with open("txsample.json", "w") as outfile:
                json.dump(logs, outfile)
                #outfile.write(logs)
            
        
            recorrido = recorrido + 1

            print (recorrido)


            if recorrido >= metros:
                verificacion = False
                print ("recorrido terminado")
    
    def codificador(self):
        pass
    
    def decodificador(self):
        pass
        
    def coordenadas(self):
        pass
    
    def bateria(self, bateria):
        self.bateria = bateria
        self.bateria = "100%"
        
        return self.bateria
        
    def ultrasonido(self):
        pass
    

robot = Robot(id_robot, pin_seguridad)

robot.run()

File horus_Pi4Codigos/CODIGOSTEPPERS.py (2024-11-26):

import RPi.GPIO as GPIO
import time

# Configura los pines
pinStep = 15
pinDirection = 14
pinStep2 = 5
pinDirection2 = 6

# Configura el modo de numeración de los pines
GPIO.setmode(GPIO.BCM)

# Configura los pines como salida
GPIO.setup(pinStep, GPIO.OUT)
GPIO.setup(pinDirection, GPIO.OUT)
GPIO.setup(pinStep2, GPIO.OUT)
GPIO.setup(pinDirection2, GPIO.OUT)

stepsPerRevolution = 200

try:
    while True:
        GPIO.output(pinDirection, GPIO.HIGH)
        GPIO.output(pinDirection2, GPIO.HIGH)

        for i in range(stepsPerRevolution):
            GPIO.output(pinStep, GPIO.HIGH)
            GPIO.output(pinStep2, GPIO.HIGH)
            print("step")
            time.sleep(0.01)  # 1 ms
            GPIO.output(pinStep, GPIO.LOW)
            GPIO.output(pinStep2, GPIO.LOW)
            time.sleep(0.01)  # 1 ms

except KeyboardInterrupt:
    pass  # Permite salir del bucle con Ctrl+C

finally:
    GPIO.cleanup()  # Limpia la configuración de los pines

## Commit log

2024-04-30 feat: conexión del backend con la base de datos de mangodb
    chore: se dividió la app en una carpeta de frontend (que contiene el código previo) y una de backend.
    Se agregó una carpeta de modelos con un esquema para la base de datos.
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2024-05-22 patch: resuelvo error de conexión con base de datos
    [index.js]
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2024-05-23 patch: resuelvo error en la comunicación con la base de datos
    [index.js]
2024-05-31 feat: implementación de electron patch: solución de error de concurrently
2024-06-10 feat: Creación de los views y html de la página. Css de Contacts
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2024-07-10 docs: Subo Anteproyecto, Historias de Usuario y Carpeta de Campo por primera vez
2024-07-31 Resuelvo error en terminaciones no identificados de los paquetes de json en el puerto serial
    [index.js, main.py]
2024-07-31 fix: Resuelvo error para el cambio de ramas
2024-07-31 fix: Cambio de ramas (parte del commit anterior)
2024-07-31 fix: Resuelvo error con la terminación de los paquetes json en la comunicación serial
    [main.py]
2024-08-02 feat: Agregando rutas de comunicación al index.js en vez de archivos separados
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2024-08-21 feat: Agrego selección y eliminación de cada categoría de filtro en ruta de data
2024-08-25 feat: Filtro con una sola categoría (date) funciona correctamente
    [index.js]
2024-08-28 Agrego filtro para más de una categoría junto con reset del filtro
    [index.js]
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2024-08-29 Ft: todo
    [Horus Stepper PCB powercont.kicad_pcb, Horus Stepper PCB powercont.kicad_sch, HorusCircuitoSteppersa4988.kicad_sch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]
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2024-09-04 fix: Arreglo orden para que inicie bien electron
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2024-09-04 Actualizo correctamente la información general del README.md
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2024-09-07 Arreglo error en el link de la pagina
2024-09-07 Revert "Arreglo error en el link de la pagina"
    This reverts commit f95c78b9b8c9a3abc59088f820d1c37c3e927f38.
2024-09-07 docs: Arreglo error en el link de la pagina
2024-09-21 Agrego templates de los perfiles para los robots y un boton para agregar (no script)
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2024-10-02 feat: agrago elemento de mapa para la home route de la libreria de leaflet para vue
2024-10-02 fix: Resuelvo problema con el mensaje que ocurre cuando no hay imagenes subidas
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2024-10-08 chore: Cambio el idioma de los elementos de la interfaz a español
2024-10-08 feat: Agrego estructura del mapa en la ruta de Home en el frontend (mapa,capas, marcadores, filtro), agrego una ruta en la api para pedir las coordenadas de todos los logs, agrego un esquema para dat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
2024-10-08 fix: Agrego parte de homeview faltante de la estructura
2024-10-22 Update: KICADPCB folder
    [Brazopcb.dsn, Brazopcb.kicad_pcb, Brazopcb.kicad_sch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]
2024-10-22 Update All Folders from Local Rep
    [Carcasa RpiPicoLoRa.stl, PAREDADELANTETERMINADAder.stl, PAREDADELANTETERMINADAizq.stl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]
2024-10-22 Create Archivo tipo .F3D
    [Archivo tipo .F3D]
2024-10-22 fix Subi mal el archivo
    [Archivo tipo .F3D]
2024-10-22 Create New Directory
    [Archivos .F3D]
2024-10-22 feat: "Añado Archivos Estructurales de HORUS"
    [adaptador eje v1.f3d, agarre de tuerca v2 brazo elevador.f3d, base brazo elevador.f3d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]
2024-10-22 feat: "Añado Archivos .F3D de la Estructura de HORUS"
    [adaptador eje v1.f3d, agarre de tuerca v2 brazo elevador.f3d, base brazo elevador.f3d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]
2024-10-22 feat: "Añado Archivos .STL de la Estructura de HORUS"
    [adaptador eje.stl, agarre resorte.stl, agarre tuerca elevador de camara.stl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]
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2024-10-28 docs: Agrego Informe presentado en la competenci feed de instagram de las ONIET
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2024-11-04 docs: Subo Carpeta de Campo actualizada y con el nombre correcto
2024-11-04 docs: Elimino Carpeta de Campo desactualizada y con un nombre que no cumple con las normas establecidas
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2024-11-07 Fix: Se añadió sin sobreescribirse
    [LORAbornernapcb.kicad_pcb, LORAbornernapcb.kicad_sch, LORAbornernapcbcorregida.kicad_pcb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]
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2024-11-07 Feat: UpToDate Carpeta PCBS kicad
    [NewEra.dsn, NewEra.kicad_pcb, NewEra.kicad_sch]
2024-11-07 Feat: Añado Placa Multipurpose
    Añado Placa multipurpose con Modificación inesperada para ser usada con Puente H, Fuí notificado de este cambio a menos de una semana del Cierre de prerequisitos y presentación de mvp
    [NewEra.dsn, NewEra.kicad_pcb, NewEra.kicad_sch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]
2024-11-07 subo parte de tapa superior
    [base atras derecha.3mf]
2024-11-07 soporte de nuevos motore
    [soport mot servoç v1.f3d]
2024-11-07 subo carcasa de arriba horus
    [tapa horus v2.f3d]
2024-11-07 soporte de motores nuevos
    [soport servoo.stl]
2024-11-08 docs: Subo Carpeta Técnica con información actualizada
    Agregamos información en el capítulo de Introducción, Sistema de Comunicación, Aplicación y IA
2024-11-08 feat: Agrego el resto de funcionalidades al mapa, e integro los perfiles de robot con servidor
    Al mapa se agregó la funcionalidad de offline como control en el propio mapa, la funcionalidad para agregar zonas de deteccion y puntos de partida aparte de las trampas, y ahora los tres marcadores s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
    El servidor ahora tiene funcionalidades para reicibir apropiadamente de la conexi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
2024-11-10 feat: Agrego eliminacion para elementos al ingresarlos y cambia las trampas a circulos
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2024-11-10 fix: soluciono error de alerts y agrego indicacion visual por error (Home)
2024-11-11 docs: Carpeta Técnica, Introducción con texto completo
    Completé infromación de adaptabilidad, objetivo, innovación, alcance y beneficios. Adjunté graficos
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2024-11-18 feat: Actualizo el codigo del modulo comunicador con codigo de los Lora
2024-11-18 fix: corrigo error en la creación de perfiles de robot
    [index.js]
2024-11-18 fix: Agrego marcador violeta para robots (mapa)
2024-11-18 fix: agrego marcador violeta para robots del mapa
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2024-11-18 fix: Arreglo error en el selector de trampa de feromona (filtro)
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2024-11-19 feat: Agrego scripts para que se pueda iniciar la app como ejecutable
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2024-11-19 fix: corrigo error de requerimientos en readme.md (app)
2024-11-19 fix: Le quito animacion de zoom al mapa para evitar errores
2024-11-20 fix: Arreglo problema con el muestreo de nuevos perfiles
2024-11-21 feat: agrego que se inserte el dia y hora desde la app y no desde el robot
2024-11-21 fix: Arreglo error de las imágenes al hacerles zoom (descentradas)
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2024-11-25 feat subo archivo stl de tensor final
    [tessor final.stl]
2024-11-25 feat subo archivo de modelado tensor definitivo
    [soporte tesnor defi v1.f3d]
2024-11-25 docs: Subo carpeta técnica con capítulos actualizados
    Capítulos de Placa Receptora y Página Web actualizados
2024-11-25 docs: Subo Carpeta Técnica con capítulos actualizados
    Actualizo capítulo de Placa Receptora y de Página Web
2024-11-25 chore: borro Carpeta Técnica mal subida
    Subí la carpeta técnica en un lugar que no debía, ya la saco
2024-11-25 Fix: carpeta clonada a la raspberry 4 y archivos actualizados a los actuales dentro de la raspberry
    [main.py, main_auxiliar.py]
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2024-11-27 docs: Tabla de costos completa
    Subo el archivo con precios parciales e individuales, en dólares y pesos, y ordenados de forma alfabética de todos los elementos comprados
2024-11-28 docs: Tabla de costos completa corregida
    Actualizo la tabla de todos los costos que requeriría recrear un robot Horus
    [Tabla costos.xlsx]
2024-11-28 docs: Tabla de costos completa corregida
    Subo la tabla de costos corregida en formato pdf
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2024-12-13 docs: Ajusto el tamaño de la imagen del grupo en el readme.md
